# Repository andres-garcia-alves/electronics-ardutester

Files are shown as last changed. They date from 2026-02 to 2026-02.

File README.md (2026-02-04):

# ArduTester v1.08k OLED

Electronic project for use an Arduino Nano as an electronics components identifier.  
Schematics diagram + PCB diagram (KiCAD 9) and case 3D model (Blender) are also provided.  

This project is a **work-in-progress**.

Based on the well-known **TransistorTester** work of [Karl-Heinz Kübbeler](https://github.com/kubi48/).

Useful links:  
- [TransistorTester oficial GitHub](https://github.com/kubi48/TransistorTester-source)  
- [Mikrocontroller.net](https://www.mikrocontroller.net/articles/AVR_Transistortester)  
- [Mikrocontroller.net GitHub](https://github.com/Mikrocontroller-net/transistortester/)  

Aditional resources:
- [Electgpl@YouTube.com: Video tutorial: ArduTester + OLED display](https://www.youtube.com/watch?v=M8jgcR9IcJU) [spanish]
- [ElProfeGarcia@YouTube.com: Video tutorial: ArduTester component tester](https://www.youtube.com/watch?v=7o1T-6169ZE) [spanish]
- [Electronoobs@YouTube.com: Video tutorial: component test with Arduino + TFT display](https://www.youtube.com/watch?v=lsy2g0oz0Dk) [spanish]
- [Electronoobs.com blog](https://electronoobs.com/eng_arduino_tut191.php) [spanish]
- [BawejaAkshay@Instructables.com: ArduTester version #1](https://www.instructables.com/Component-Tester-Test-Almost-Anything-/)
- [BawejaAkshay@Instructables.com: ArduTester version #2](https://www.instructables.com/Component-Tester-in-a-Keychain/)
- [Lithium-Ion@Hackster.io blog](https://www.hackster.io/LithiumION/minimal-component-tester-using-arduino-b7b960)
- [RiverTrue@DFRobot.com blog](https://community.dfrobot.com/makelog-312328.html)
- [Plouc68000@ProjectHub.arduino.cc blog](https://projecthub.arduino.cc/plouc68000/ardutester-v113-the-arduino-uno-transistor-tester-2deffc)
- [ChristianIhle@GitHub.com blog](https://github.com/blurpy/transistor-tester)

&nbsp;

This project comes in two versions: `standard` (current) and `extended` (planned). See features bellow.

Features:
- One-key-operation.
- Three test pins for universal use.
- Automated detection of pin assignment, this means the device-under-test can be connected to the tester in any order.

Supported components:
- `Diodes`, `LEDs` and `Zeners`.
  - Diodes will also be displayed with their correctly aligned symbol, pin number, voltage drop, the parasitic capacitance and reverse current will also be measured.
- `Transistors` NPN/PNP BJT, JFET, N-channel/P-channel MOSFET.
  - Measurement of hFE and base-emitter-voltage for bipolar junction transistors, also for Darlingtons.
  - Automated detection of protection diodes in bipolar junction transistors and MOSFETs.
  - Bipolar junction transistors are detected as a transistor with a parasitic transistor (NPNp = NPN + parasitic PNP).
- `Resistors` will be measured with a resolution down to 0.1 ohm.  
  The measurement range is up to 50 Mohm (Megaohm).  
  Resistors below 10 ohm will be measured with the ESR approach and a resolution of 0.01 ohm.
- `Capacitors` in the range 35pF (picofarad) to 100mF (millifarad) can be measured with a resolution down to 1 pF.
  - Measurement of ESR (Equivalent Series Resistance) of capacitors greater than 20 nF is built in. 
  - Vloss of capacitors greater 5 nF is examined. With this it is possible to estimate its Q-factor.
- Resistors and capacitors will be displayed with their respective symbol, pin number and value.
- `Inductances` of 0.01 mH to 20 H can be detected and measured.
- Small `Thyristors` and `TRIACs`.

Notes:
- Be sure to **discharge capacitors** before measure it. Existing voltage can damage your Arduino.

&nbsp;

### List of Materials

The `standard` version uses the following electronic components:
- 1 x Arduino Nano v3
- 1 x OLED display 0.96" 128x64 I2C
- 3 x 680 ohm resistor
- 3 x 470k ohm resistor
- 1 x Push switch button
- 1 x 10k ohm resistor
- 1 x Socket connector 5-pins
- 1 x Bornier connector 2-pins / JST connector 2-pins
- 1 x Bornier connector 3-pins / JST connector 3-pins
- 1 x Bornier connector 4-pins / JST connector 4-pins
- Wires

&nbsp;

### Screenshots

| Breadboard | Assembly |
|---|---|
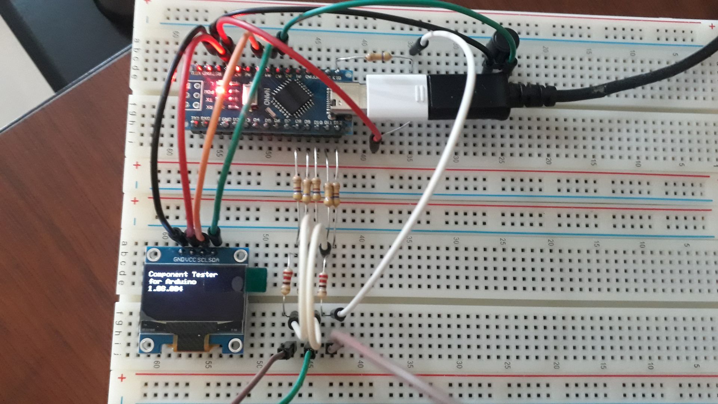
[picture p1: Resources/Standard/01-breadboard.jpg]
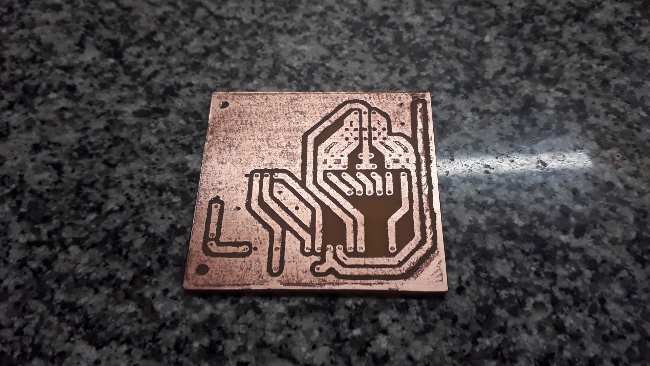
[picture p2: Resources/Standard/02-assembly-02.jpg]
|  |  |

| Assembly | Assembly |
|---|---|
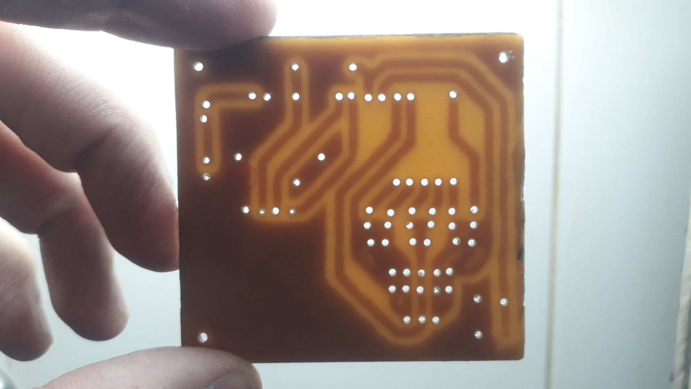
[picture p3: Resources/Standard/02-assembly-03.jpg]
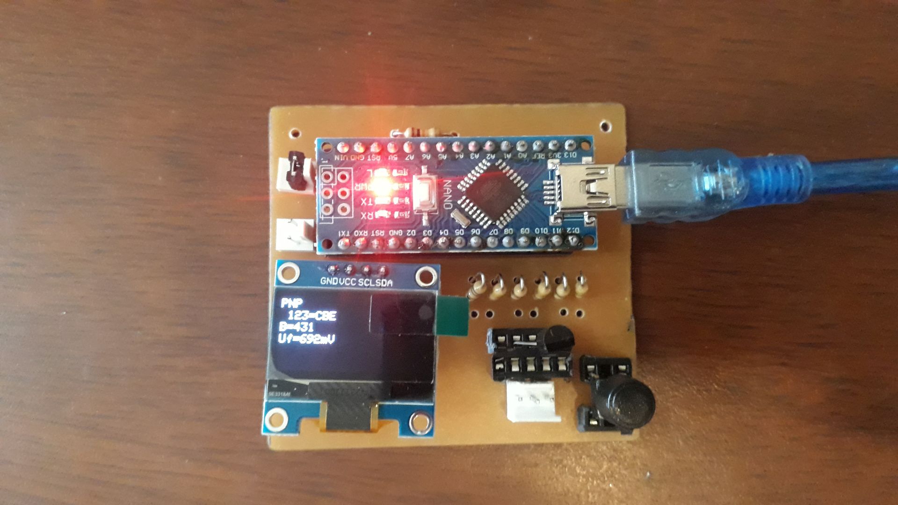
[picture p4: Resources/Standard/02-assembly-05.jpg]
|  |  |

| Schematics Diagram | PCB Diagram |
|---|---|
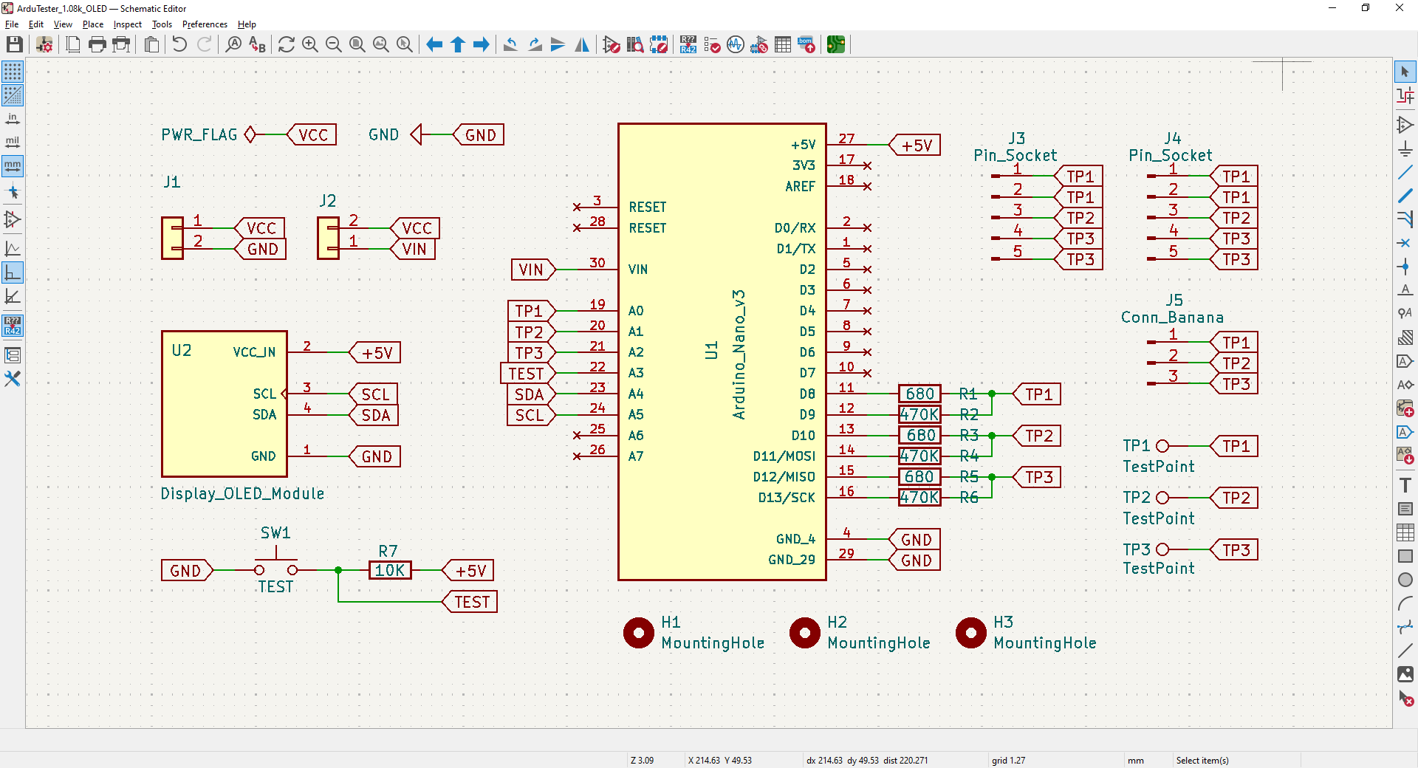
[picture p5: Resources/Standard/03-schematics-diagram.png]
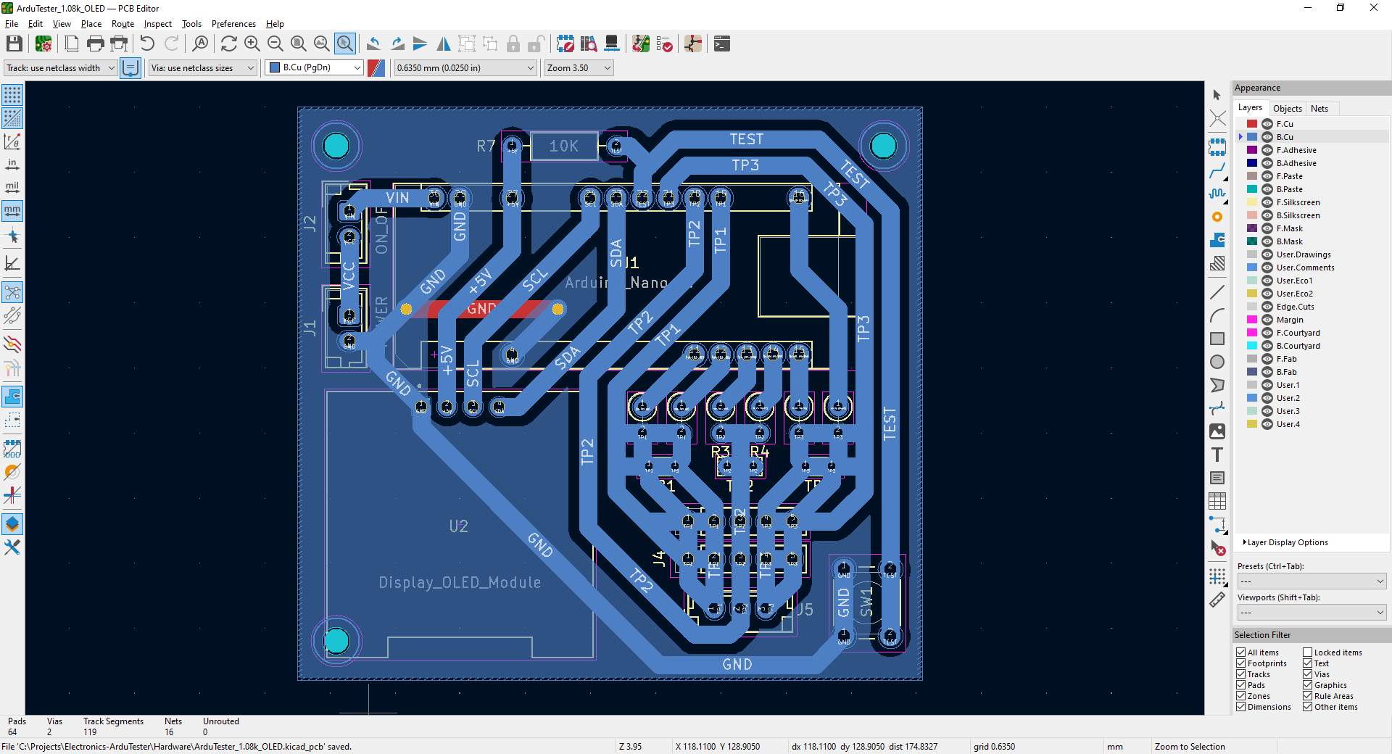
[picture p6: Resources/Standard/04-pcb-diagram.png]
|  |  |

| PCB Render 3D | PCB Render 3D |
|---|---|
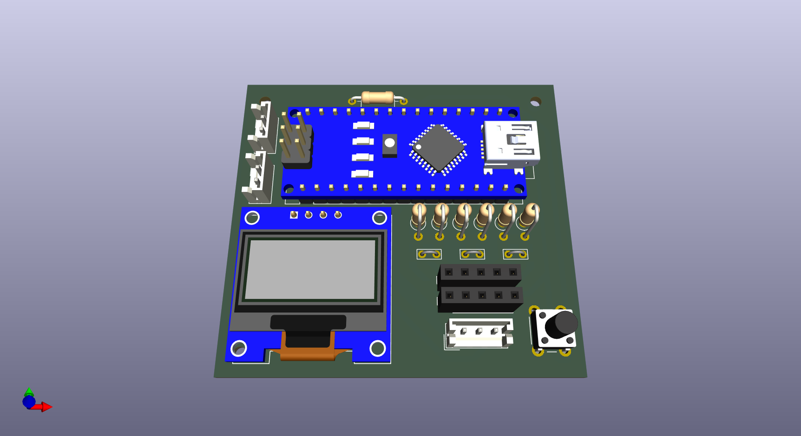
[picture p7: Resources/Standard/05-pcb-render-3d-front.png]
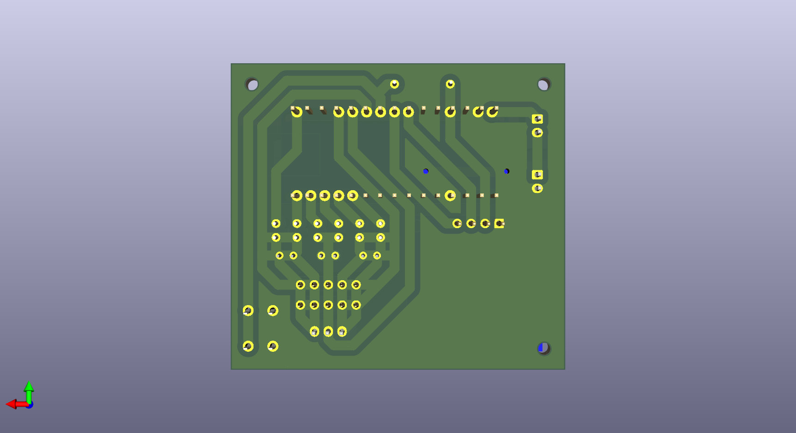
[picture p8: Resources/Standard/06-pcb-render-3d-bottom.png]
|  |   |

| Case 3D Model | Project Final |
|---|---|
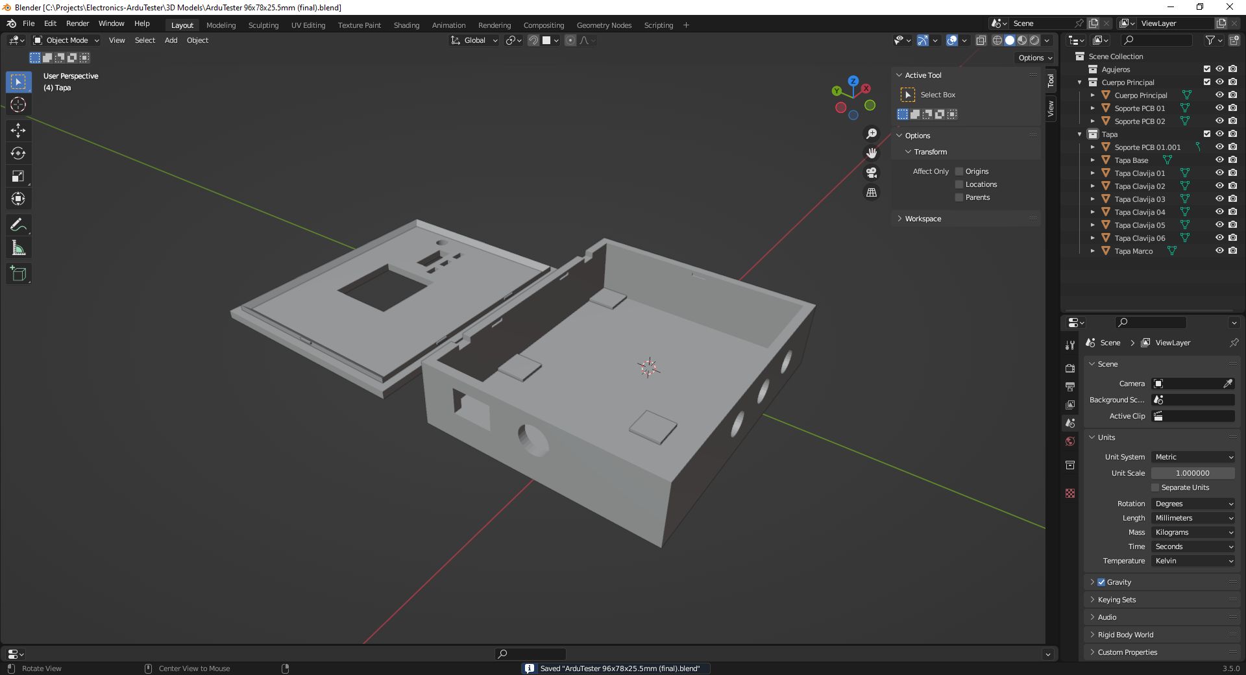
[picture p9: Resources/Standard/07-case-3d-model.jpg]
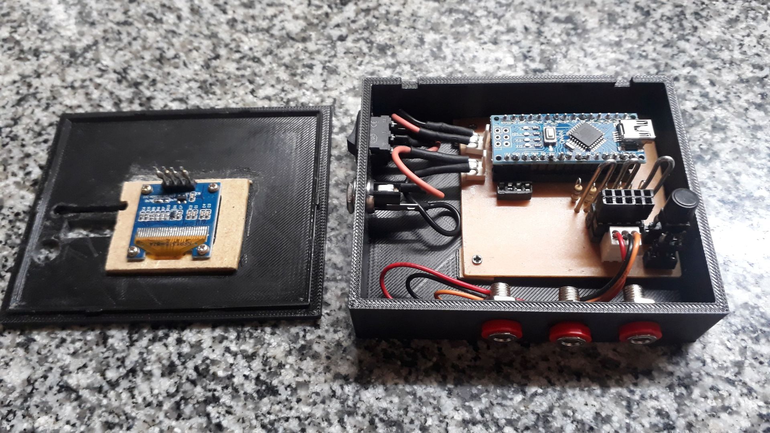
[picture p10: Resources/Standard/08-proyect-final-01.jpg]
|  |  |

| Project Final | Project Final |
|---|---|
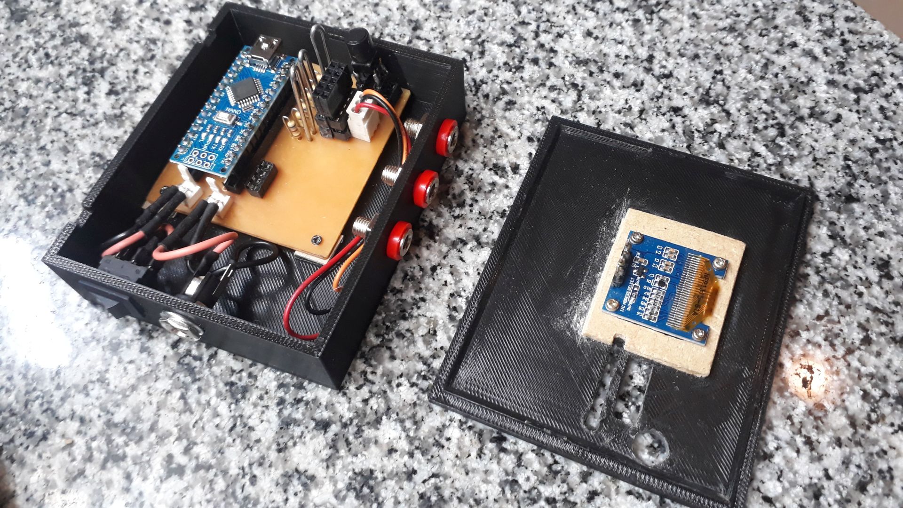
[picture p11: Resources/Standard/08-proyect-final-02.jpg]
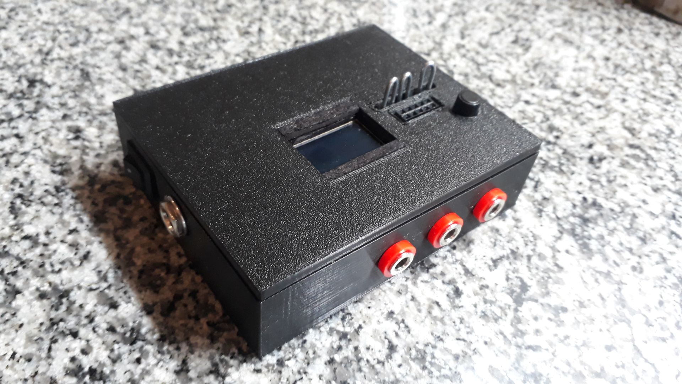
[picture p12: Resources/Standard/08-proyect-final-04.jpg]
|  |  |

See 'Resources' sub-folder for more pictures & videos of the project.

&nbsp;

### Version History

v1.0 (2026.01.04) - Initial release.  
v1.1 (2026.01.05) - Added schematics and PCB diagrams.  
v1.2 (2026.01.05) - Added 3D case model.  
v1.3 (2026.01.06) - Firmware and PCB fixes.  
v1.4 (2026.01.06) - 3D case model fixes.  
v1.4 (2026.01.06) - Minor case 3D model fixes.  
v1.5 (2026.01.09) - Minor fixes on PCB.  
v1.6 (2026.01.14) - Minor fixes on PCB.  
v1.7 (2026.01.16) - Re-design of PCB and 3D case model.  
v1.8 (2026.02.03) - Minor cases 3D model fixes.  
v1.9 (2026.02.04) - Added gadget images & video.  

&nbsp;

This source code is licensed under GPL v3.0  
Please send me your feedback about this project: andres.garcia.alves@gmail.com

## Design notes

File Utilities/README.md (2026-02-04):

## 🧪 Prueba A - Lectura de PINB (Entrada flotante)

📌 Objetivo

Verificar que los pines digitales D8–D13 (PB0–PB5) funcionen como entradas de alta impedancia cuando no hay nada conectado.

Sirve para detectar:
- Pull-ups internos activados permanentemente
- Puentes internos entre pines
- Fuga hacia GND o VCC
- PUERTO B dañado

🧠 Comportamiento esperado

En un Arduino sano:
- Los bits cambian continuamente
- No hay patrón fijo
- Algunos HIGH, otros LOW
- Excepción: pueden dat todos LOW según el Arduino (0)

En un Arduino dañado:
- Todo HIGH (111111)
- Patrón fijo que nunca cambia

🧾 Código:
<pre>
void setup() {
    Serial.begin(9600);
    DDRB = 0x00; // PB0–PB5 como entradas
}

void loop() {
    Serial.println(PINB & 0x3F, BIN);   // Lee solo PB0–PB5 delay(300);
}
</pre>

&nbsp;

## 🔁 Prueba B — PORTB salida → entrada (Test de conmutación digital)

📌 Objetivo:

Confirmar que los pines D8–D13 pueden:
- Conducir correctamente LOW y HIGH.
- Reflejar ese estado al leer PINB.

Detecta:
- Transistores MOSFET de salida quemados
- Pines pegados HIGH o LOW
- Puentes internos
- Fallo parcial de lógica digital

🧠 Comportamiento esperado

En un Arduino sano:
000000  
111111  
000000  
111111  
...

En un Arduino dañado:
- No cambia entre 0 y 1
- Bits faltantes (101011)
- Siempre HIGH o siempre LOW

🧾 Código
<pre>
void setup() {
    Serial.begin(9600);
    DDRB = 0x3F; // PB0–PB5 como salidas
}

void loop() {
    PORTB = 0x00;
    Serial.println(PINB & 0x3F, BIN);
    delay(300);
    PORTB = 0x3F;
    Serial.println(PINB & 0x3F, BIN);
    delay(300);
}
</pre>

&nbsp;

## 🎯 Prueba C — ADC A0/A1/A2 en vacío (Diagnóstico Analógico)

📌 Objetivo

Validar el sistema analógico completo:
- Multiplexor ADC (MUX)
- Capacitor Sample & Hold
- Comparador interno
- Referencia y acople entre canales

Detecta:
- ADC quemado por sobrevoltaje
- Fuga interna al VCC/GND
- MUX corrompido
- Diodos de protección dañados

🧠 Comportamiento esperado

En un Arduino sano:
- Números aleatorios
- Diferentes entre sí
- Rango típico: 50–600
- Cambian frame a frame

Ejemplo válido:
80   140  210
300   70  400
55   350  120

En un Arduino dañado:
- valores pegados a ~1023 → fuga a VCC
- valores pegados a ~0 → fuga a GND
- los tres iguales → crosstalk permanente

🧾 Código
<pre>
void setup() {
    Serial.begin(9600);
}

void loop() {
    Serial.print(analogRead(A0));
    Serial.print("\t");
    Serial.print(analogRead(A1));
    Serial.print("\t");
    Serial.println(analogRead(A2));
    delay(300);
}
</pre>

&nbsp;

## 🏁 Cómo usar los tres tests

1️⃣ Cargar Prueba A
✔ caos de bits → OK
✘ patrón fijo → no sirve para ArduTester

2️⃣ Si pasó, cargar Prueba B
✔ 0 ↔ 1 alterna completo → OK
✘ bits clavados → puerto digital dañado

3️⃣ Si pasó, cargar Prueba C
✔ ruido analógico variable → Nano apto
✘ todos iguales / 0 / 1023 → ADC dañado

&nbsp;

## 🏆 Conclusión

Si un Nano pasa los tres diagnósticos, está 100% apto para:
- ArduTester
- Medición analógica seria
- Proyectos con sensores
- Cualquier diseño donde se necesite precisión
- Si falla solo C, pero pasa A/B → podés usarlo para proyectos digitales solamente.

&nbsp;

## 🚀 Secuencia Automática

<pre>
// -----------------------------------------------------------
// SKETCH DIAGNÓSTICO PARA NANO
// Prueba A: Entrada flotante en PB (D8–D13)
// Prueba B: Conmutación digital LOW/HIGH en PB
// Prueba C: ADC en vacío (A0-A1-A2)
// Autor: armado especialmente para validar ArduTester
// -----------------------------------------------------------
void printBanner(const char *msg) {
    Serial.println();
    Serial.println(F("================================"));
    Serial.println(msg);
    Serial.println(F("================================"));
}
// -----------------------------------------------------------
// PRUEBA A — PB como entradas, lectura flotante
// -----------------------------------------------------------
void testA() {
    printBanner("PRUEBA A - Entrada flotante PB0-PB5");
    DDRB = 0x00; // D8-D13 como entradas
    for (int i = 0; i < 6; i++) {
        Serial.print("PINB = ");
        Serial.println(PINB & 0x3F, BIN);
        delay(300);
    }
}
// -----------------------------------------------------------
// PRUEBA B — PB como salida, alternando LOW/HIGH
// -----------------------------------------------------------
void testB() {
    printBanner("PRUEBA B - Conmutación PB0-PB5");
    DDRB = 0x3F; // D8-D13 como salidas
    for (int i = 0; i < 6; i++) {
        PORTB = 0x00;
        Serial.print("LOW -> ");
        Serial.println(PINB & 0x3F, BIN);
        delay(300);
        PORTB = 0x3F;
        Serial.print("HIGH -> ");
        Serial.println(PINB & 0x3F, BIN);
        delay(300);
    }
}
// -----------------------------------------------------------
// PRUEBA C — ADC en vacío A0/A1/A2
// -----------------------------------------------------------
void testC() {
    printBanner("PRUEBA C - Lectura ADC A0/A1/A2");
    for (int i = 0; i < 20; i++) {
        Serial.print(analogRead(A0));
        Serial.print("\t");
        Serial.print(analogRead(A1));
        Serial.print("\t");
        Serial.println(analogRead(A2));
        delay(300);
    }
}
void setup() {
    Serial.begin(9600);
    delay(1000);
    Serial.println();
    Serial.println(F("=== TEST COMPLETO DE ARDUINO NANO ==="));
    Serial.println(F("Ejecutando las 3 pruebas en bucle..."));
    Serial.println();
}
void loop() {
    testA();
    delay(800);
    testB();
    delay(800);
    testC();
    delay(1500);
    printBanner("FIN CICLO - Repitiendo");
    delay(5000);
}

</pre>

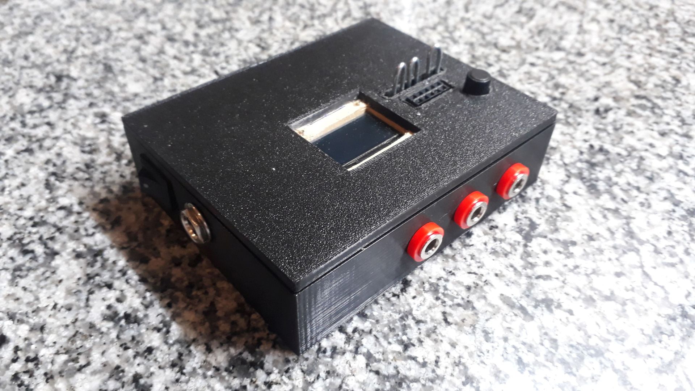
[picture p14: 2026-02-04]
Resources/Standard/08-proyect-final-03.jpg

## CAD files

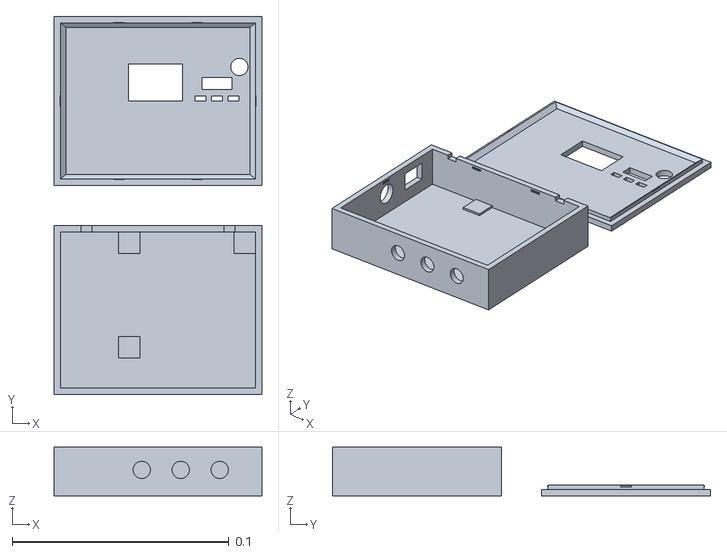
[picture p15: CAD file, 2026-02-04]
3D Models/ArduTester 96x78x25.5mm (final).stl
0.096 x 0.175 x 0.0225

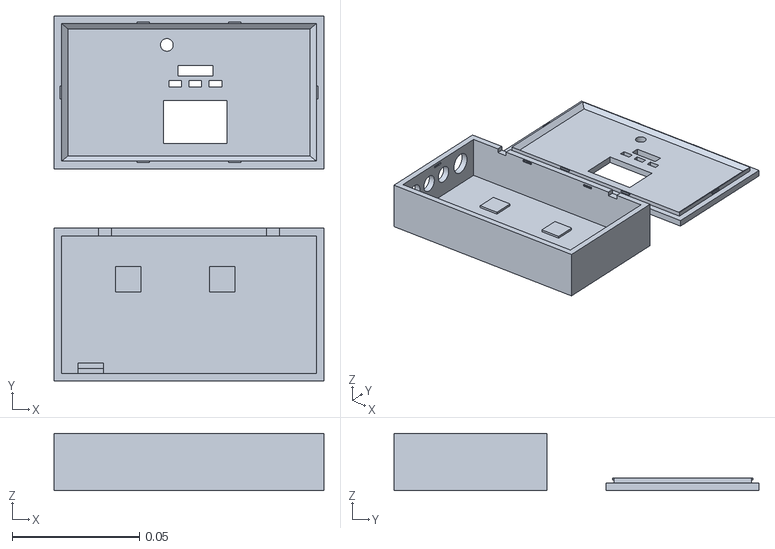
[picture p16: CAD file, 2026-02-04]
3D Models/ArduTester (Internal 9V Battery) 106x60x25.5mm (final).stl
0.106 x 0.143 x 0.0225

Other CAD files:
3D Models/ArduTester (Internal 9V Battery) 106x60x25.5mm (final).blend
3D Models/ArduTester (Internal 9V Battery) 106x60x25.5mm (without holes).blend
3D Models/ArduTester 96x78x25.5mm (final).blend
3D Models/ArduTester 96x78x25.5mm (without holes).blend

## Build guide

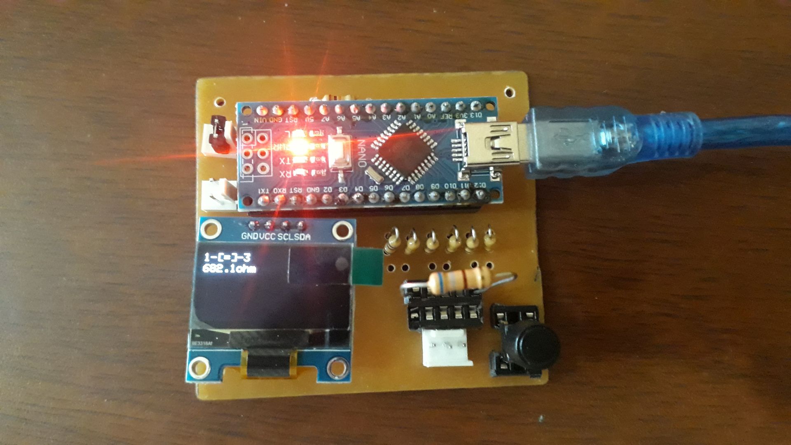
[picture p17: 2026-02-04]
Resources/Standard/02-assembly-04.jpg

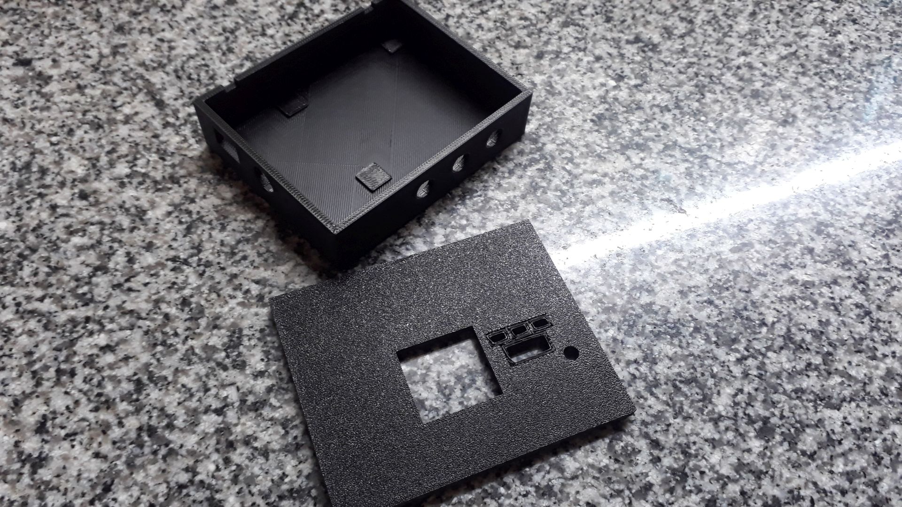
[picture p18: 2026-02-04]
Resources/Standard/07-case-3d-print.jpg

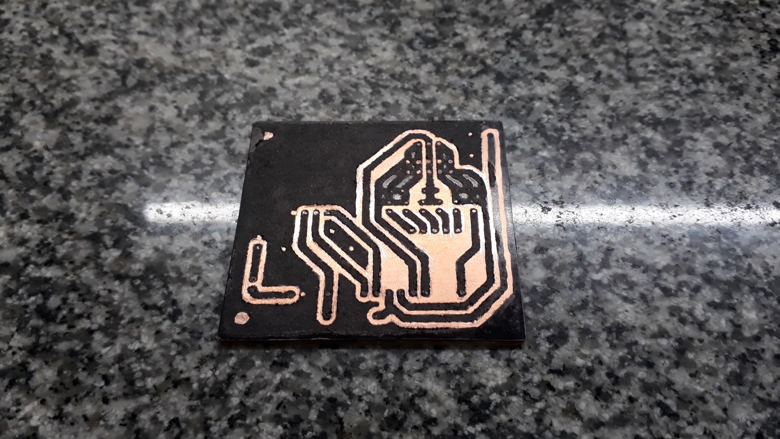
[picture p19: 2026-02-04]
Resources/Standard/02-assembly-01.jpg

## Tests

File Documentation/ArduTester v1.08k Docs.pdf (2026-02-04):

# TransistorTester with AVR microcontroller and a little more Version 1.08k

### Karl-Heinz K¨ubbeler

kh kuebbeler@web.de

### September 25, 2013

# Contents

1 Features | 4
2 Hardware | 7
3 Instructions for use | 15
4 Configuring the TransistorTester | 19
5 Description of the measurement procedures | 24

5.5 Selftest Function | 66
5.5.1 | Some Results of the Selftest Function | 70
6 Known errors and unsolved problems | 73
7 Special Software Parts | 74
8 To Do List and new ideas | 75

## Preface

### Basically Motive

Every hobbyist knows the following problem: You disassemle a Transistor out of a printed board or you get one out of a collection box. If you find out the identification number and you already have a data sheet or you can get the documents about this part, everything is well. But if you don’t find any documents, you have no idea, what kind of part this can be. With conventional approach of measurement it is difficult and time-consuming to find out the type of the part and parameters. It could be a NPN, PNP, N- or P-Channel-Mosfet etc. It was the idea of Markus F. to hand over the work to a AVR microcontroller.

### As my work has started

My work with the software of the TransistorTester of Markus F. [1] has started, because I had problems with my programmer. I had bought a printed board and components, but I could not program the EEprom of the ATmega8 with the Windows driver without error messages. Therefore I took the software of Markus F. and changed all the accesses from the EEprom memory to flash memory accesses. By analysing the software in order to save memory at other places of program, I had the idea, to change the result of the ReadADC function from ADC units to millivolt (mV) units. The mV resolution is needed for any output of voltage values. If ReadADC returns directly the mV resolution, I can save the conversion for each output value. This mV resolution can be get, if you first accumulate the results of 22 ADC readings. The sum must be multiplied with two and divided by nine. Then we have a maximum value of 1023·22·2
9 = 5001, which matches perfect to the wanted mV resolution of measured voltage values. So I additionally had the hope, that the enhancement of ADC resolution by oversampling could help to improve the voltage reading of the ADC, as described in AVR121 [5]. The original version ReadADC has accumulated the result of 20 ADC measurements and divides afterwards by 20, so the result is equal to original ADC resolution. By this way never a enhancement of ADC resolution can take place. So I had to do little work to change the ReadADC, but this forced analysing the whole program and change of all “if-statements” in the program, where voltage values are queried. But this was only the beginning of my work!

More and more ideas to make measurement faster and more accurate has been implemented. Additionally the range of resistor and capacity measurements are extended. The output format for LCD-Display was changed, so symbols are taken for diodes, resistors and capacitors instead of text. For further details take a look to the actual feature list chapter 1. Planned work and new ideas are accumulated in the To Do List in chapter 8. By the way, now I can program the EEprom of the ATmega with Linux operating system without errors.
At this place I would like to thank the originator and software author Markus Frejek, who has enabled the continuation with his initial work. In addition I would like to say thanks to the authors of numerous input to the discussion forum, which have assist me, to find new tasks, weak points and errors. Next I would like to thank Markus Reschke, who give me the permission, to publish his cheerful software versions at the SVN server. Furthermore some ideas and software part of Markus
R. was integrated in my own software version, again thank you very much. I have to thank also Asco B., who has developed a new printed board, to enable the reproductions for other hobbyists. Another thank I would like to send to Dirk W. , who has handled the omnibus order for this printed board. Never I had time anough to handle these things concurrently with my software developement, at no time the state of further developement of software would have the same level. Thanks for the many suggestions to improve the tester to the members of the local chapter of the ”Deutscher Amateur Radio Club (DARC)” in Lennestadt.

# Chapter 1

# Features

1. Operates with ATmega8, ATmega168 or ATmega328 microcontrollers.
2. Displaying the results to a 2x16 character LCD-Display.
3. One key operation with automatic power shutdown.
4. Battery operation is possible since shutdown current is only about 20nA.
5. Low cost version is feasible without crystal and auto power off. With software version 1.05k the sleep modus of the Atmega168 or ATmega328 is used to reduce current if no measurement is required.
6. Automatic detection of NPN and PNP bipolar transistors, N- and P-Channel MOSFETs, JFETs, diodes, double diodes, Thyristors and Triacs.
7. Automatic detection of pin layout of the detected part.
8. Measuring of current amplification factor and Base-Emitter threshold voltage of bipolar transistors.
9. Darlington transistors can be identified by the threshold voltage and high current amplification factor.
10. Detection of the protection diode of bipolar transistors and MOSFETs.
11. Measuring of the Gate threshold voltage and Gate capacity value of MOSFETs.
12. Up to two Resistors are measured and shown with symbols | and values with up to four
decimal digits in the right dimension. All symbols are surrounded by the probe numbers of the Tester (1-3). So Potentiometer can also be measured. If the Potentiometer is adjusted to one of its ends, the Tester cannot differ the middle pin and the end pin.
13. Resolution of resistor measurement is now up to 0.01Ω, values up to 50MΩ are detected.
14. One capacitor can be detected and measured. It is shown with symbol and value with up to four decimal digits in the right dimension. The value can be from 25pF (8MHz clock, 50pF @1MHz clock) to 100mF. The resolution can be up to 1 pF (@8MHz clock].
15. For capacitors with a capacity value above 0.18µF the Equivalent Serial Resistance (ESR) is measured with a resolution of 0.01Ω and shown with two significant decimal digits. This feature is only avaiable for ATmega with at least 16K flash memory (ATmega168 or ATmega328).

16. For capacitors with a capacity value above 5000pF the voltage loss after a load pulse can be determined. The voltage loss give a hint for the quality factor of the capacitor.
17. Up to two diodes are shown with symbol | or symbol | in correct order. Additionally
the flux voltages are shown.
18. LED is detected as diode, the flux voltage is much higher than normal. Two-in-one LEDs are also detected as two diodes.
19. Zener-Diodes can be detected, if reverse break down Voltage is below 4.5V. These are shown as two diodes, you can identify this part only by the voltages. The outer probe numbers, which surround the diode symbols, are identical in this case. You can identify the real Anode of the diode only by the one with break down (threshold) Voltage nearby 700mV!
20. If more than 3 diode type parts are detected, the number of founded diodes is shown additionally to the fail message. This can only happen, if Diodes are attached to all three probes and at least one is a Z-Diode. In this case you should only connect two probes and start measurement again, one after the other.
21. Measurement of the capacity value of a single diode in reverse direction. Bipolar Transistors can also be analysed, if you connect the Base and only one of Collector or Emitter.
22. Only one measurement is needed to find out the connections of a bridge rectifier.
23. Capacitors with value below 25pF are usually not detectet, but can be measured together with a parallel diode or a parallel capacitor with at least 25pF. In this case you must subtract the capacity value of the parallel connected part.
24. For resistors below 2100Ω also the measurement of inductance will be done, if your ATmega has at least 16K flash memory. The range will be from about 0.01mH to more than 20H, but the accuracy is not good. The measurement result is only shown with a single component connected.
25. Testing time is about two seconds, only capacity or inductance measurement can cause longer period.
26. Software can be configured to enable series of measurements before power will be shut down.
27. Build in selftest function with optional 50Hz Frequency generator to check the accuracy of clock frequency and wait calls (ATmega168 and ATmega328 only).
28. Selectable facility to calibrate the internal port resistance of port output and the zero offset of capacity measurement with the selftest (ATmega168 and ATmega328 only). A external capacitor with a value between 100nF and 20µF connected to pin 1 and pin 3 is necessary to compensate the offset voltage of the analog comparator. This can reduce measurement errors of capacitors of up to 40µF. With the same capacitor a correction voltage to the internal reference voltage is found to adjust the gain for ADC measuring with the internal reference.

Thyristors and Triacs can only be detected, if the test current is above the holding current. Some Thyristors and Triacs need as higher gate trigger current, than this Tester can deliver. The available testing current is only about 6mA! Notice that all features can only be used with microcontroller with more program memory such as ATmega168.

Attention: Allways be shure to discharge capacitors before connecting them to the Tester! The Tester may be damaged before you have switched it on. There is only a little protection at the ATmega ports.
Extra causion is required if you try to test components mounted in a circuit. In either case the equipment should be disconnected from power source and you should be shure, that no residual voltage remains in the equipment.

# Chapter 2

# Hardware

## 2.1 Circuit of the TransistorTester

The circuit of the TransistorTester in figure 2.1 is based on the circuit of Markus F. released in Abb. 1 of AVR-Transistortester report [1]. Changed or moved parts are marked with green color, optional parts are marked with red color.
Some changes are made because the electronical power switch make problems in some implemen-tations. Therefore the resistor R7 is reduced to 3.3kΩ. The capacitor C2 is reduced to 10nF and R8 is moved so that the PD6 output does not try to switch the C2 capacitor directly. Additional blocking capacitors are added and should be placed near the power connection of the Atmega and near the Voltage regulator.
Because the PD7 input and PC6 (RESET) are the only pins, where pull up resistors where needed, one extra 27kΩ resistor is added to the PD7 (pin 13) input. With this modification the software can disable all internal pull up resistors of the ATmega.
The additional crystal with its 22pF capacitors are optional added. The accuracy of a crystal has the benefit of more stable time measurement for getting the capacitor values.
New software version can use a voltage scale switch of the ADC. The speed of switching is reduced by the external capacitor C1 at the AREF (21) pin of the ATmega. To avoid slowing down the measurement speed more than necessary, the value of this capacitor should be reduced to 1nF. Removing of the capacitor C1 is also possible. For adapting the software to the actual circuit take a look to the Makefile options in the configuring chapter 4.
Some different versions of R11 / R12 resistor combinations circulates in the internet. I have adapted my software to the original of Markus F. [1] with 10kΩ and 3.3kΩ.
The additional 2.5V precision voltage reference connected at pin PC4 (ADC4) can be used to check and calibrate the VCC voltage, but is not required. You can use a LM4040-AIZ2.5 (0.1%), a LT1004CZ-2.5 (0.8%) or a LM336-Z2.5 (0.8%) as voltage reference. A optional ISP connector has been added to easier load new software versions to the tester.

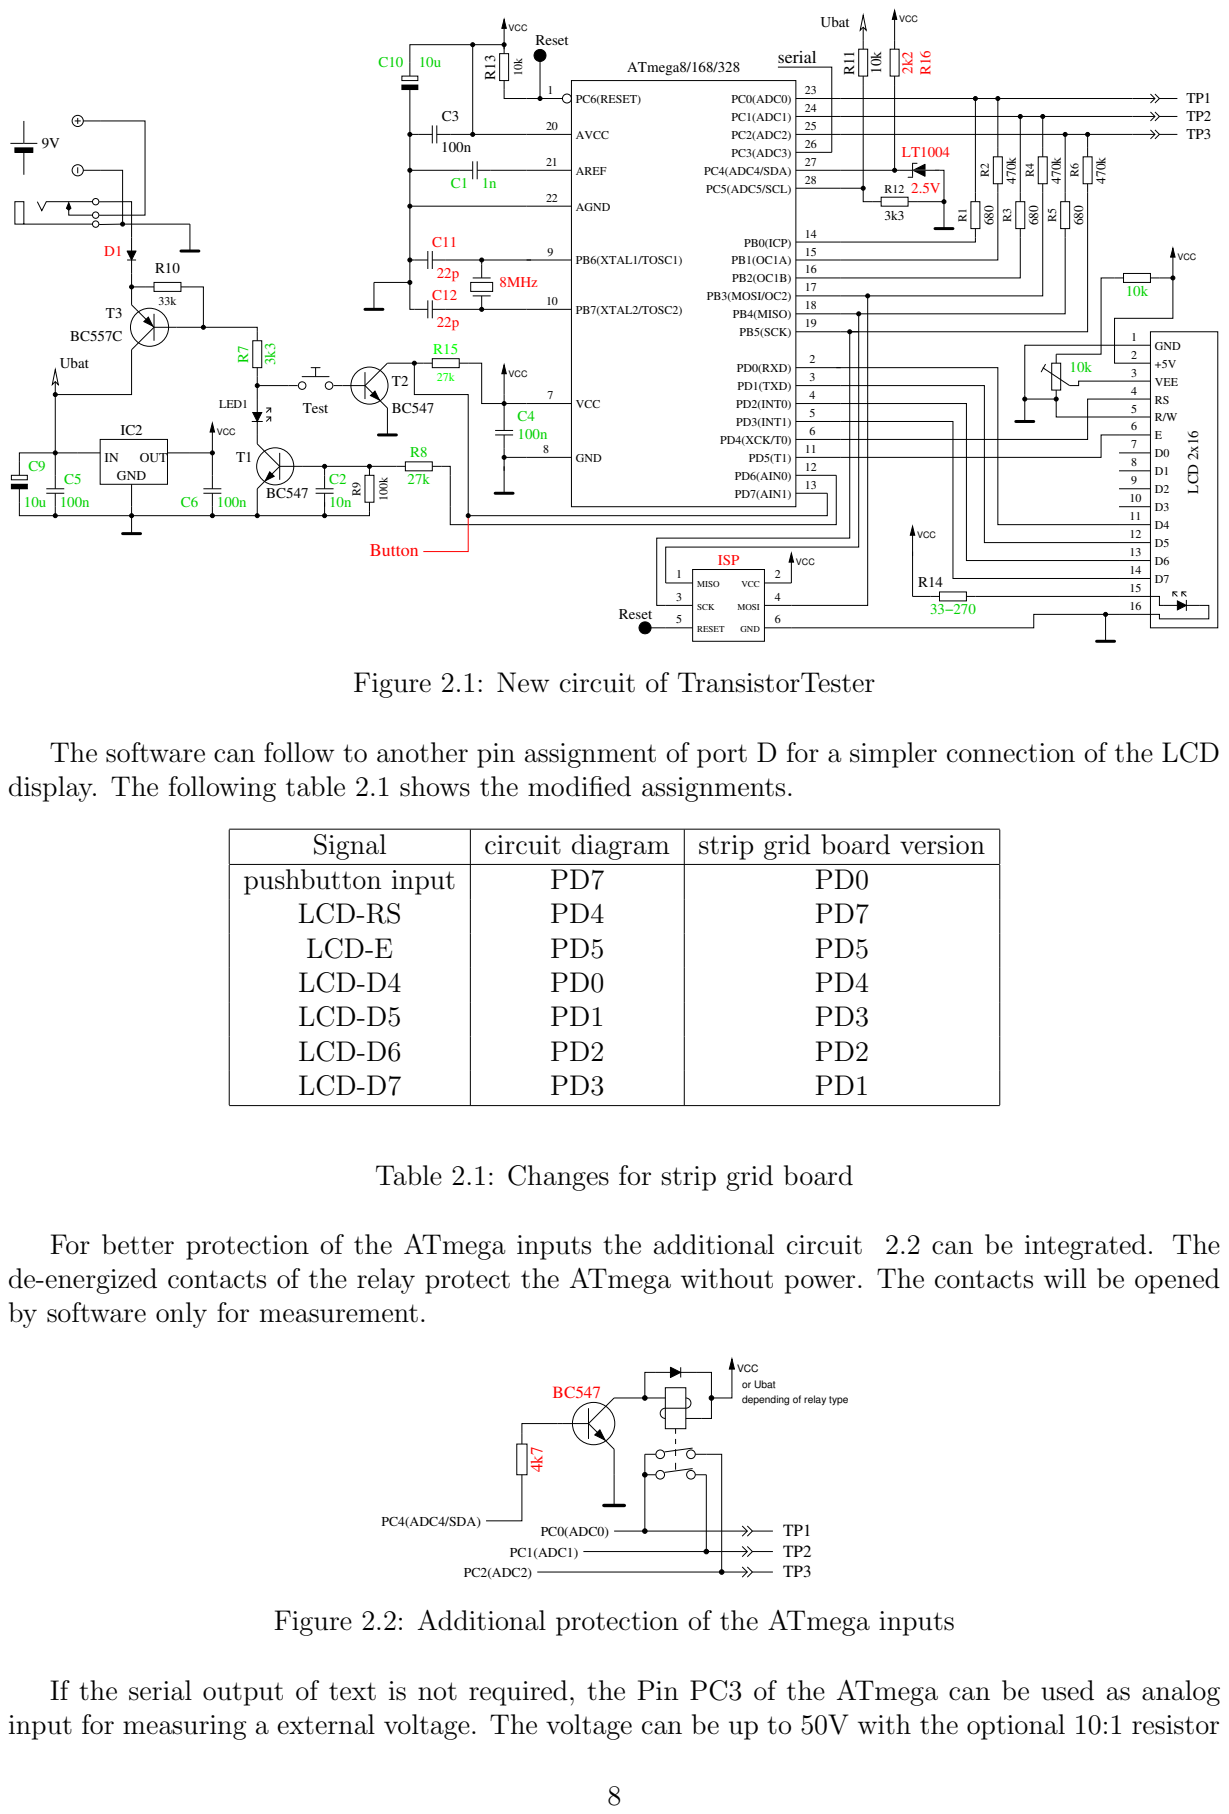
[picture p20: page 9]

Figure 2.1: New circuit of TransistorTester

The software can follow to another pin assignment of port D for a simpler connection of the LCD
display. The following table 2.1 shows the modified assignments.

Signal | circuit diagram | strip grid board version
pushbutton input LCD-RS LCD-E LCD-D4 LCD-D5 LCD-D6 LCD-D7 | PD7 PD4 PD5 PD0 PD1 PD2 PD3 | PD0 PD7 PD5 PD4 PD3 PD2 PD1

Table 2.1: Changes for strip grid board

For better protection of the ATmega inputs the additional circuit 2.2 can be integrated. The
de-energized contacts of the relay protect the ATmega without power. The contacts will be opened
by software only for measurement.

VCC Figure 2.2: Additional protection of the ATmega inputs

or Ubat
depending of relay type

If the serial output of text is not required, the Pin PC3 of the ATmega can be used as analog
input for measuring a external voltage. The voltage can be up to 50V with the optional 10:1 resistor

divider and can be used for measuring the breakdown voltage of a zener diode. A current limiting power supply with up to 50V can be switched on with low signal at PD7 pin of the ATmega to deliver current for testing the break down voltage of a zener diode. Figure 2.3 shows a suggestion for this expansion. The tester shows the external voltage as long as you hold the key pressed. About 40mA more battery current is used by this expansion during key pressing.

Vin+

Vin−

Com DC−DC Conv.

Vout+15

Vout−15

R18

180k

R17

20k

10n

serial / PC3

External
Voltage

1uF

33uH

L1

C13

Uext
10k

TMA0515D

T4
Uext

Button

R19

Ubat

C15

100n

Can be placed on Tester board! Should be placed separate!

IN OUT

IC3

GND

MCP1702

IRFU9024

C17

C16

50u 100n
C14

Figure 2.3: Expansion for measuring of break down voltage of Zener diodes

## 2.2 Hints for building the TransistorTester

Every LCD-display with at least 2x16 character and a HD44780 compatible controller can be used with the TransistorTester. You should respect the current needed for illumination, some LCD need lower current than others. I had tried OLED type displays, but this type cause interference with measurements of the ATmega and are not recommended. Also loading of special characters for displaying the resistor symbol has caused problems with the OLED.
The resistors R1 to R6 are critical for measurements and this 680Ω and 470kΩ resistors should be measurement type resistors (tolerance of 0.1%) to get the full accuracy. You should use a precision socket for the ATmega microcontroller to enable the replacement of the microcontroller. The microcontroller ATmega8, ATmega168 and ATmega328 can be used. Recommended is a ATmega168 or ATmega328, if you wish to use all features.
Anyway you should assemble all parts to printed board without the microcontroller. A up-to-date low voltage drop regulator like MCP1702-5002 is recommended as IC2, because it need only 2µA of standby current and can still deliver 5V, if your input voltage is only 5.4V. But this part is not pin compatible to well known 78L05 with TO92 body!
After checking, that all needed parts are at the correct place, you should first connect the battery or power supply to the printed board without LCD-display and microcontroller. You should check the voltage at the power pins of the microcontroller and LCD-display terminal during the Test key is pressed. The voltage should disappear, if you release the Test key. If the voltage had correct polarity and value, you should disconnect the power and assemble the microcontroller with correct alignment. Be careful and make shure, that all pins of the microcontroller are in the socket holes. Now you can also connect the LCD. Check if power pins of the LCD has the right connection to GND and VCC of your board.
If you are shure that everything is all right, reconnect the power. If you have already programmed the ATmega, you can press the Test button. By pressing the Test key, the background light of the LCD should switch on. If you release the Test button, the LED should illuminate weak. Notice, that the software for the microcontroller must be compiled for the correct processor type. A program for the ATmega8 does not run on a ATmega168!

2.3 Changeover for tester versions designed by Markus F.

Voltage control If the problem exist, the tester will shut down immediately with every switch on. With imy suggested setting of the fuses (Makefile) the voltage control of the different ATmega versions is switched to 4V (brown out level). This may be the reason why the tester makes trouble with the power on sequence. The Pin PD6 tries to switch the 100nF capacitor C2 to VCC level causing a voltage breakdown of the VCC voltage (5V). The capacitor C2 can be reduced to <10nF without problems. If possible, the direct connection of PD6 should be replaced by a resistor >220Ω.

Improvement of power on circuit Often this problem is the reason, if the tester starts with the button hold pressed, but switch off directly by releasing. The problem is enforced by a high current background light for the LCD. The resistor R7 to the base of the PNP transistor T3 was optimized with the value 27kΩ too much to save power consuming. To improve the switching with lower battery voltage or lower current amplification factor of the PNP transistor T3, you should reduce the resistance to 3.3kΩ.

Additional pull-up resistor at PD7 The missing pull-up resistor results to a switch off of the tester with the message ”Timeout” after a short display time. The software is configured with the option PULLUP DISABLE, that all internal pull-up resistors are switched off. For that reason the voltage of pin PD7 is not definded, if the level is not switched by the push button or transistor T2 to GND. One external pull-up resistor of 27kΩ to VCC avoid this error.

Capacitor C1 at the AREF pin Many designs use a 100nF capacitor at the AREF pin, like the design of Markus F. too. As long as the reference voltage of the ADC is never changed, this is a good solution. The software of the TransistorTester for the ATmega168/328 uses a automatic selection of the internal 1.1 V reference voltage of the ADC, if the input voltage is below 1V. With this solution a better resolution of the ADC can be reached for little input voltages. Unfortunately the switching from 5V to 1.1V reference is very slowly. A additional wait time of 10ms must be respected for this reason. With changing the capacity value to 1nF this wait time can be reduced significant. I have not noticed any degration of measurement quality with this change. Even a removing of the capacitor has no significant change of measurement results. If you prefer to leve the capacitor unchanged, you can remove the option NO AREF CAP in the Makefile to activate longer wait times in the program.

Expanding of a 8MHz crystal With some skill you can expand a 8MHz crystal to the backside of the printed board directly to the pins PB6 and PB7 (pin 9 and pin 10). My own expansion was done without the both 22pF capacitors. This solution has operated well with all tested ATmega. But it is not required to use a crystal. You can still use the 8MHz RC oszillator by setting the fuses to get the better resolution of time constant measuring (capacity value).

Smoothing of the operating voltage The original circuit of Markus F. shows only one 100nF capacitor to block the VCC voltage. This is clearly too little smoothing. You should at least use one 100nF near the ATmega power pins and one near the voltage regulator. The input of the voltage regulator should be blocked with a 100nF too. Additional 10µF capacitors (electrolytic or ceramic) at the input and output of the voltage regulator can stable the voltage level. Ceramic 10µF capacitos with SMD mounting form are easier to use for backfitting and have usually a lower ESR value.

Selection of the ATmega processor The using of the base function of the tester is still possible with a ATmega8. The flash memory of that device is used near 100% . Because the ATmega168 or ATmeg328 processors are pin-compatible to the ATmega8, I can recommend the replacement. Actually the price for ATmega328 is so cheap, that there is no reason to take a ATmega168 type. With a ATmega168/328 you get the following advantages: Self test with automatic calibration.
Improvement of measurement quality by automatic switching of ADC scale.

Measurement of inductors with resistance below 2100Ω. Measurement of ESR value of capacitors with value of above 0.18µF. The resolution of resistor measurement below 10Ω is 0.01Ω.
Using of pin PC4 as serial output.

Missing precision voltage reference Usually the software should detect the missing voltage reference with the unconnected pin PC4. In this case no VCC=x.xV message should appear in row 2 of the LCD on power on. If this message appear without the reference, you should connect a 2.2kΩ resistor to the PC4 input and VCC.

## 2.4 Chinese clones

As I know, the tester is rebuild in China in two versions. The first model is rebuild from the first design of Markus F. without the ISP port. The assembled ATmega8 is placed in a socket, so you can replace it with a ATmega168 or ATmega328. For this version you should consider all the hints of section 2.3. Additional 100nF ceramic cpacitors should be connected near by the VCC-GND and AVCC-GND pins of the ATmega for better stabilization of the power voltage. In addition you should notice, that if you expand the board with the additional 8 MHz crystal, your external ISP programmer must have a external clock for programming.

The second version of rebuilded tester is build with SMD components. Also the fix installed ATmega168 is a SMD type with 32TQFP body. Fortunately on the board is a 10-pole ISP connector provided for the programming. I have analysed the board version ”2.1 2012/11/06”. One error is the assembly of the part ”D1”, which should be a precision 2.5V voltage reference. Assembled is only a zener diode. This part should be removed. You can mount a LM4040AIZ2.5 or LT1004CZ-2.5 precision voltage reference at this place. A missing voltage reference is noticed by the software, so that you must not install the voltage reference. My exemplar was delivered with software version 1.02k. The 10-pole ISP plug was not assembled and I must install a jumper from ISP pin 6 to ISP pin
10. My programmer expect a GND connection at pin 10, but the board has GND level only on pin 4 and pin 6 of the ISP. The label of the ATmega168 was rub away and there was no documentation delivered with the part. The lock fuses of the ATmega were set, so no readout was possible. But I could install the software version 1.05k without any problems. Another user has problems with the same software version 1.05k. This user has the chinese board ”2.2 2012/11/26”. The software runs only without problems, if a additional 100nF keramic capacitor was placed between the pin 18-AVCC and 21-GND near by the ATmega. The software 1.05k uses the sleep state of the ATmega for waiting time. For this reason the current alternates often and the voltage regulator is stressed more. Further I have noticed, that the VCC voltage is blocked with a 100nF ceramic capacitor and with a 220µF electrolytic capacitor nearby the 78L05 voltage regulator. The 9V supply voltage is blocked with the same capacitors, but not at the input of the regulator but at the emitter of the PNP transistor (parallel with the battery). The printed circuit board track from the ATmega168 to the test port is very thin, so that a resistance of 100mΩ could be measured for one path. This will be the reason for measuring a resistance of 0.3Ω for two direct connected pins. The ESR measuring can usually consider this by zero compensation. Beginning with version 1.07k the software does respect this offset for measuring resistors below 10Ω too.
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

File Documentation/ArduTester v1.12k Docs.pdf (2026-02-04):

# TransistorTester with AVR microcontroller and a little more Version 1.12k

### Karl-Heinz K¨ubbeler

kh kuebbeler@web.de

### February 18, 2017

# Contents

1 Features | 5
2 Hardware | 9
3 Instructions for use | 38
4 Configuring the TransistorTester | 47

5 Description of the measurement procedures | 58
5.1 Measurement of Semiconductors | 60
5.1.1 | Measurement of PNP Transistor or P-Channel-MOSFET | 61
5.1.2 | Measurement of NPN Transistor or N-Channel-MOSFET | 63
5.1.3 | Simplified flowchart of the transistors tests | 66
5.1.4 | Measurement of Diodes | 68
5.1.5 | Results of different measurements | 69
5.2 Resistor Measurement | 73
5.2.1 | Resistor Measurement with 680 Ohm Resistors | 73
5.2.2 | Resistor Measurement with 470 kOhm resistors | 75
5.2.3 | Results of the resistor measurements | 76
5.3 Measurement of Capacitors | 81
5.3.1 | Discharging of Capacitors | 81
5.3.2 | Measurement of big Capacitors | 81
5.3.3 | Measurement of small Capacitors | 84
5.3.4 | Measurement of very small capacity values with the sampling technique . . . . 86
5.3.5 | Measurement of the Equivalent Series Resistance ESR | 87
5.3.6 | Measurement of the Equivalent Series Resistance ESR, first way | 89
5.3.7 | Measurement of the Equivalent Series Resistance ESR, second way | 92
5.3.8 | Voltage loss after a load pulse, Vloss | 99
5.3.9 | Separate capacity and ESR measurement | 100
5.3.10 Results of Capacitor measurement | 101
5.3.11 Automatic calibration of the capacitor measurement | 105
5.4 Measurement of inductance | 109
5.4.1 | Results of the inductance measurements | 110
5.4.2 | Measurement of small inductances with the sampling method | 110
5.5 Selftest Function | 112
5.5.1 Some Results of the Selftest Function | 116
5.6 Measurement of frequency | 120
6 Signal generation | 122
6.1 Frequency Generation | 122
6.2 Puls width generation | 122
7 Known errors and unsolved problems | 123
8 Special Software Parts | 124
9 To Do List and new ideas | 125

## Preface

### Basically Motive

Every hobbyist knows the following problem: You disassemle a Transistor out of a printed board or you get one out of a collection box. If you find out the identification number and you already have a data sheet or you can get the documents about this part, everything is well. But if you don’t find any documents, you have no idea, what kind of part this can be. With conventional approach of measurement it is difficult and time-consuming to find out the type of the part and parameters. It could be a NPN, PNP, N- or P-Channel-Mosfet etc. It was the idea of Markus F. to hand over the work to a AVR microcontroller.

### As my work has started

My work with the software of the TransistorTester of Markus F. [1] has started, because I had problems with my programmer. I had bought a printed board and components, but I could not program the EEprom of the ATmega8 with the Windows driver without error messages. Therefore I took the software of Markus F. and changed all the accesses from the EEprom memory to flash memory accesses. By analysing the software in order to save memory at other places of program, I had the idea, to change the result of the ReadADC function from ADC units to millivolt (mV) units. The mV resolution is needed for any output of voltage values. If ReadADC returns directly the mV resolution, I can save the conversion for each output value. This mV resolution can be get, if you first accumulate the results of 22 ADC readings. The sum must be multiplied with two and divided by nine. Then we have a maximum value of 1023·22·2
9 = 5001, which matches perfect to the wanted mV resolution of measured voltage values. So I additionally had the hope, that the enhancement of ADC resolution by oversampling could help to improve the voltage reading of the ADC, as described in AVR121 [5]. The original version ReadADC has accumulated the result of 20 ADC measurements and divides afterwards by 20, so the result is equal to original ADC resolution. By this way never a enhancement of ADC resolution can take place. So I had to do little work to change the ReadADC, but this forced analysing the whole program and change of all “if-statements” in the program, where voltage values are queried. But this was only the beginning of my work!

More and more ideas to make measurement faster and more accurate has been implemented. Additionally the range of resistor and capacity measurements are extended. The output format for LCD-Display was changed, so symbols are taken for diodes, resistors and capacitors instead of text. For further details take a look to the actual feature list chapter 1. Planned work and new ideas are accumulated in the To Do List in chapter 9. By the way, now I can program the EEprom of the ATmega with Linux operating system without errors.
At this place I would like to thank the originator and software author Markus Frejek, who has enabled the continuation with his initial work. In addition I would like to say thanks to the authors of numerous input to the discussion forum, which have assist me, to find new tasks, weak points and errors. Next I would like to thank Markus Reschke, who give me the permission, to publish his cheerful software versions at the SVN server. Furthermore some ideas and software part of Markus R. was integrated in my own software version, again thank you very much. Also Wolfgang SCH. has done a great job to support a graphical display with ST7565 controller. Many thanks to him for integrating his patch for 1.10k software version to the actual developer version. I have to thank also Asco B., who has developed a new printed board, to enable the reproductions for other hobbyists. Another thank I would like to send to Dirk W. , who has handled the omnibus order for this printed board. Never I had time anough to handle these things concurrently with my software developement, at no time the state of further developement of software would have the same level. Thanks for the many suggestions to improve the tester to the members of the local chapter of the

”Deutscher Amateur Radio Club (DARC)” in Lennestadt. Also I would like to say thanks for the integration of the sampling method to the radio amateur Pieter-Tjerk (PA3FWM). With this method the measurement of little capacity and inductance values could be improved noticeable. Last but not least I would say thanks to Nick L. from Ukraine, who has supported my with his prototype boards, has suggested some hardware add ons and also has organized the russian translation for this description.

# Chapter 1

# Features

1. Operates with ATmega8, ATmega168 or ATmega328 microcontrollers. Additionally ATmega644, ATmega1284, ATmega1280 or ATmega2560 microcontrollers can be used.
2. Displaying the results to a 2x16 or a 4x16 character LCD-Display. If the processor have at least 32K flash memory, also a graphical display with 128x64 pixel and a ST7565, ST7920, ST7108, KS0108 or a SSD1306 controller can be used. In doing so a 4-wire SPI interface or a I

2C bus must be used instead of the 4-bit parallel interface for the SSD1306 controller. Even color displays with ILI9163 or ST7735 controller are usable with the SPI interface. For the ST7108 or KS0108 controller you must use a serial - parallel interface with a 74HC(T)164 or a 74HC(T)595. Displays with PCF8812 or PCF8814 controller can be only used without the big icons for transistors, because the display size is unsufficient (102x65 and 96x65).

3. One key operation with automatic power shutdown.
4. Battery operation is possible since shutdown current is only about 20nA.
5. Low cost version is feasible without crystal and auto power off. With software version 1.05k the sleep modus of the Atmega is used to reduce current if no measurement is required and no rotary encoder is used (not with ATmega8).
6. Automatic detection of NPN and PNP bipolar transistors, N- and P-Channel MOSFETs, JFETs, diodes, double diodes,N- and P-IGBTs, Thyristors and Triacs. For Thyristors and Triacs the ignition current and holding current must be reached with the tester. For IGBTs the 5V signal should be enough for driving the gate voltage.
7. Automatic detection of pin layout of the detected part.
8. Measuring of current amplification factor and Base-Emitter threshold voltage of bipolar transistors.
9. Darlington transistors can be identified by the threshold voltage and high current amplification factor.
10. Detection of the protection diode of bipolar transistors and MOSFETs.
11. Measuring of the Gate threshold voltage, the Gate capacity value and the RDSon at almost 5V gate voltage of MOSFETs.
12. Up to two Resistors are measured and shown with symbols | and values with up to four
decimal digits in the right dimension. All symbols are surrounded by the probe numbers of the Tester (1-3). So Potentiometer can also be measured. If the Potentiometer is adjusted to one of its ends, the Tester cannot differ the middle pin and the end pin.

13. Resolution of resistor measurement is now up to 0.01Ω, values up to 50MΩ are detected.
14. One capacitor can be detected and measured. It is shown with symbol | and value with
up to four decimal digits in the right dimension. The value can be from 25pF (8MHz clock, 50pF @1MHz clock) to 100mF. The resolution can be up to 1pF (@8MHz clock].
15. For capacitors with a capacity value above 20nF the Equivalent Serial Resistance (ESR) is measured with a resolution of 0.01Ω and is shown with two significant decimal digits. This feature is only available for ATmega with at least 16K flash memory.
16. For capacitors with a capacity value above 5000pF the voltage loss after a load pulse can be determined. The voltage loss give a hint for the quality factor of the capacitor.
17. Up to two diodes are shown with symbol | or symbol | in correct order. Additionally
the flux voltages are shown.
18. LED is detected as diode, the flux voltage is much higher than normal. Two-in-one LEDs are also detected as two diodes.
19. Zener-Diodes can be detected, if reverse break down Voltage is below 4.5V . These are shown as two diodes, you can identify this part only by the voltages. The outer probe numbers, which surround the diode symbols, are identical in this case. You can identify the real Anode of the diode only by the one with break down (threshold) Voltage nearby 700mV !
20. If more than 3 diode type parts are detected, the number of founded diodes is shown additionally to the fail message. This can only happen, if Diodes are attached to all three probes and at least one is a Z-Diode. In this case you should only connect two probes and start measurement again, one after the other.
21. Measurement of the capacity value of a single diode in reverse direction. Bipolar Transistors can also be analysed, if you connect the Base and only one of Collector or Emitter. If a ATmega with more than 8K flash memory is used, also the reverse current of the diode is measured with a resolution of 2nA. The value is only output to the screen, if it is greater than zero.
22. Only one measurement is needed to find out the connections of a bridge rectifier.
23. Capacitors with value below 25pF are usually not detectet, but can be measured together with a parallel diode or a parallel capacitor with at least 25pF. In this case you must subtract the capacity value of the parallel connected part. For processors with at least 32K flash memory the tester changeover to a special capacity meter function, if a capacitor with more than 25pF is once measured at TP1 and TP3. In this capacitor meter mode you can measure capacitors below 25pF at TP1 and TP3 directly.
24. For resistors below 2100Ω also the measurement of inductance will be done, if your ATmega
has at least 16K flash memory. For that a inductor icon | is shown behind the resistor
icon | . The range will be from about 0.01mH to more than 20H, but the accuracy is
not good. The measurement result is only shown with a single component connected.
25. Testing time is about two seconds, only capacity or inductance measurement can cause longer period.
26. Software can be configured to enable series of measurements before power will be shut down.
27. Build in selftest function with optional 50Hz Frequency generator to check the accuracy of clock frequency and wait calls (only for processors with at least 32K flash memory).

28. Selectable facility to calibrate the internal port resistance of port output and the zero offset of capacity measurement with the selftest (only for processors with at least 16K flash memory). A external capacitor with a value between 100nF and 20µF connected to pin 1 and pin 3 is necessary to compensate the offset voltage of the analog comparator. This can reduce measurement errors of capacitors of up to 40µF. With the same capacitor a correction voltage to the internal reference voltage is found to adjust the gain for ADC measuring with the internal reference.
29. Display the Collector cutoff current ICE0 with currentless base (1µA units) and Collector residual current ICES with base hold to emitter level (only for processors with at least 16K flash). This values are only shown, if they are not zero (especially for Germanium transistors).
30. For a ATmega with at least 32K flash memory the tester changes the operation modus from universal tester to a resistor tester, if only one resistor is detected at the test pin 1 (TP1) and test pin 3 (TP3). If you have selected the additional measurement of inductance for the resistor meter function with the Makefile option RMETER WITH L, also the inductance of components is measured in this mode. This special operating mode is indicated with a [R] or [RL] at the right side of the first display line. In the same way the tester changes to a capacity meter function, if a capacitor is detected at TP1 and TP3. This operation mode is indicated with a [C] at the right side of the first display line. With this capacity meter function capacity values are shown down to 1pF. Only for the automatic start you need a capacitor with more than 25pF. Both special modes can be finished by a key press. The tester will then continue with the normal tester function.
31. For processors with at least 32K flash a dialog function can be selected, which enable additional functions. Of course you can return from dialog to the normal Transistor Tester function.
32. With dialog function you can use a frequency measurement at port PD4 of the ATmega. The resolution is 1Hz for input frequencies above 25kHz. For lower frequencies the resolution can be up to 0.001mHz by measuring the mean period. You should read the the subsection Frequency measurement 2.2.4 at page 13 for details of connection a frequency signal.
33. With the dialog function and without the activated serial output a external voltage of up to 50V can be measured with the 10:1 voltage divider at the PC3 port. If the PLCC-Version of the ATmega328 is used, one of the additional pins can be used for the voltage measurement together with the serial output. If the zener diode measurement extension (DC-DC converter) is assembled, the measurement of zener diodes is also possible with this function by pressing the key.
34. With the dialog function a frequency output can be selected at the TP2 pin (PB2 Port of the ATmega). Currently a preselection of frequencies from 1Hz up to 2MHz can be selected.
35. With the dialog function a fixed frequency output with selectable pulse width can be activated at the TP2 pin (PB2 port of the ATmega). The width can be enhanced with 1% by a short key press or with 10% by a longer key press.
36. With the dialog function can be started a separated capacity measurement with ESR measurement. Capacities from about 2µF up to 50mF can most be measured in circuit, because only a little measurement voltage of about 300mV is used.
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

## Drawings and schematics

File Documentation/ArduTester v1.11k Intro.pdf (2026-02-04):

# Short description of the measurements with the Transistor Tester Version 1.11k

### Karl-Heinz K”ubbeler

kh kuebbeler@web.de

### March 16, 2021

# Contents

1 Description of BJT-measurements | 2
2 Description of MOSFET measurements | 6

# Chapter 1

# Description of BJT-measurements

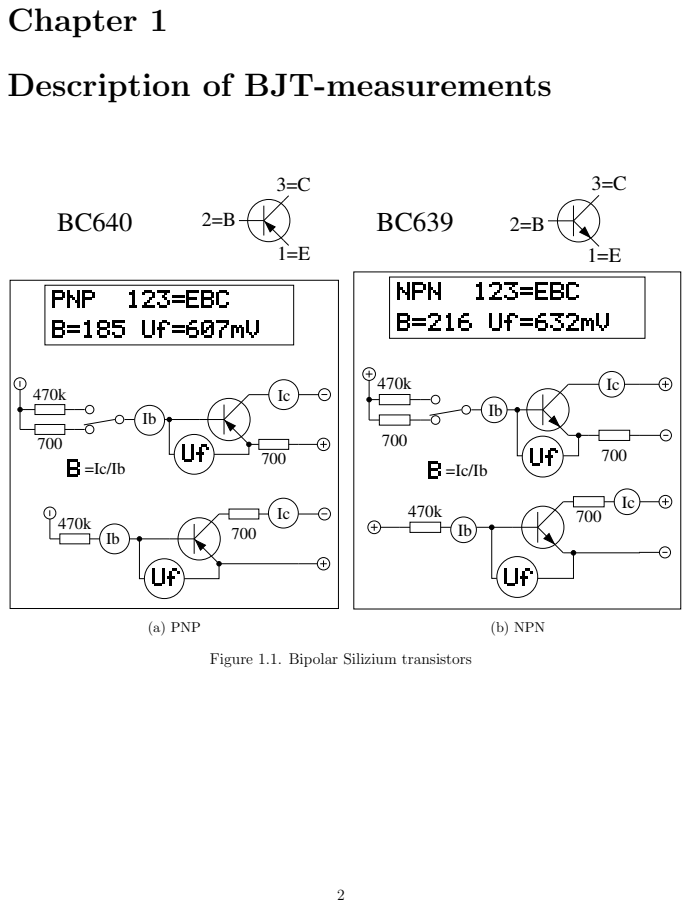
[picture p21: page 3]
(a) PNP; (b) NPN

Figure 1.1. Bipolar Silizium transistors

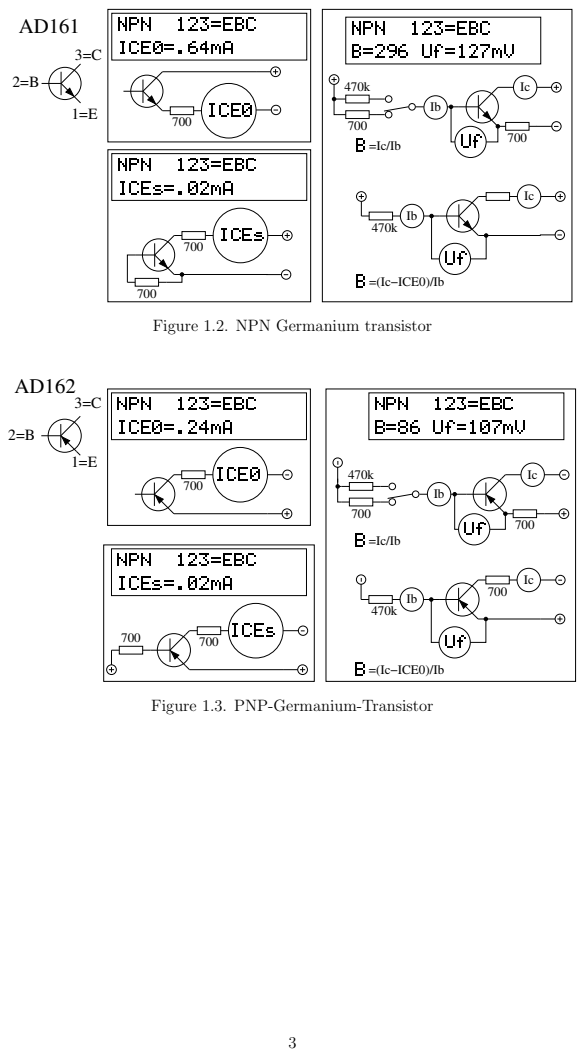
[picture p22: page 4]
=(Ic−ICE0)/Ib

Figure 1.2. NPN Germanium transistor

Figure 1.3. PNP-Germanium-Transistor

BC516

BC517

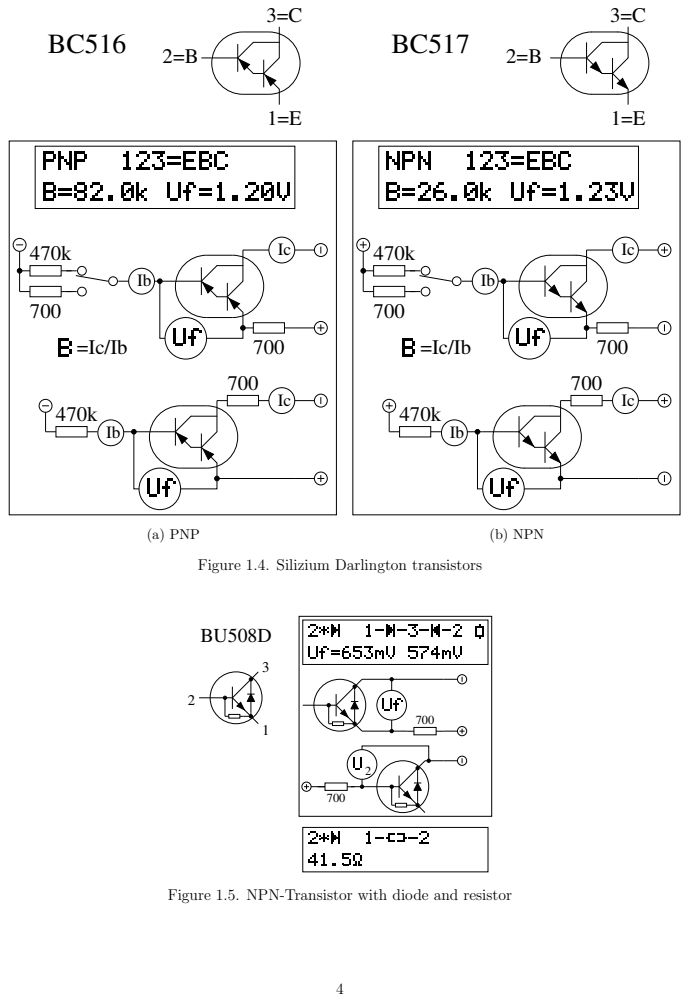
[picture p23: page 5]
(a) PNP; (b) NPN

Figure 1.4. Silizium Darlington transistors

Figure 1.5. NPN-Transistor with diode and resistor

## BDV64C

## BDV65C

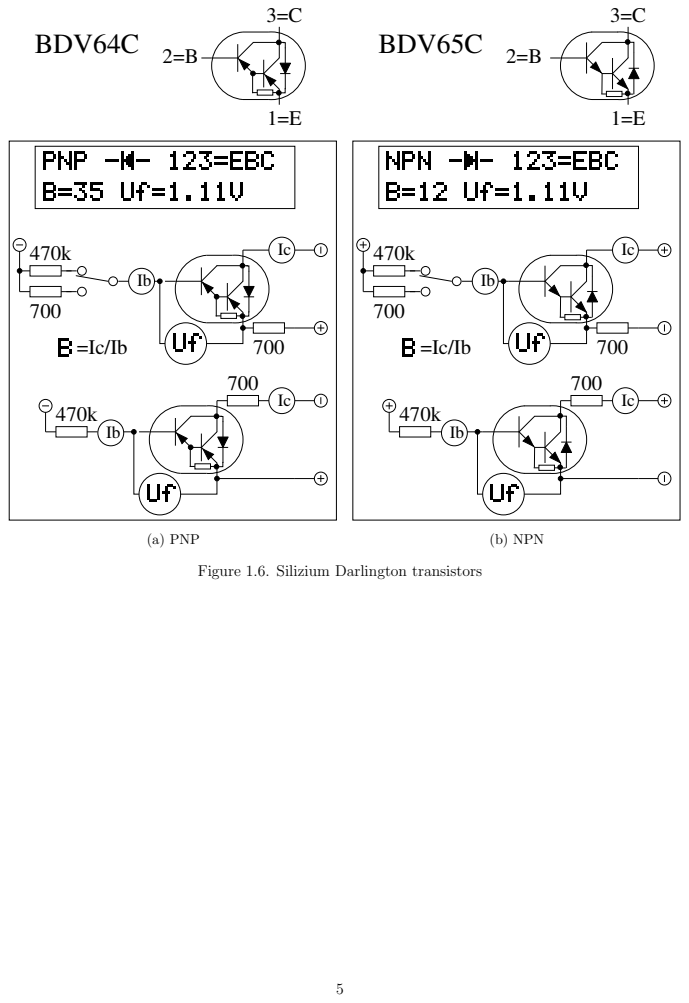
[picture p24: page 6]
(a) PNP; (b) NPN

Figure 1.6. Silizium Darlington transistors

# Chapter 2

# Description of MOSFET measurements

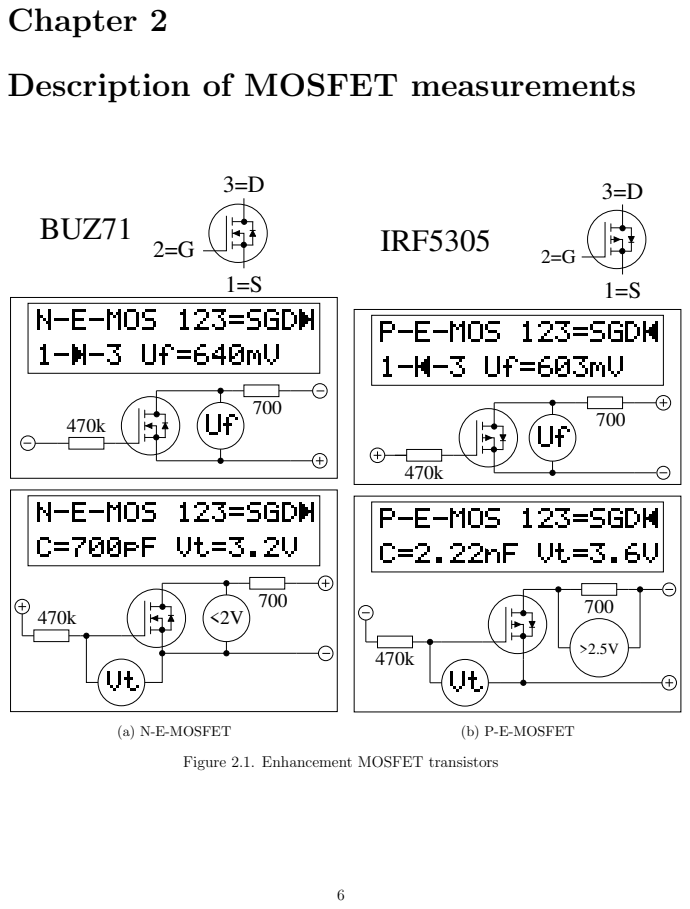
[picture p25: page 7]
BUZ71; (a) N-E-MOSFET; 2=G IRF5305; (b) P-E-MOSFET

Figure 2.1. Enhancement MOSFET transistors

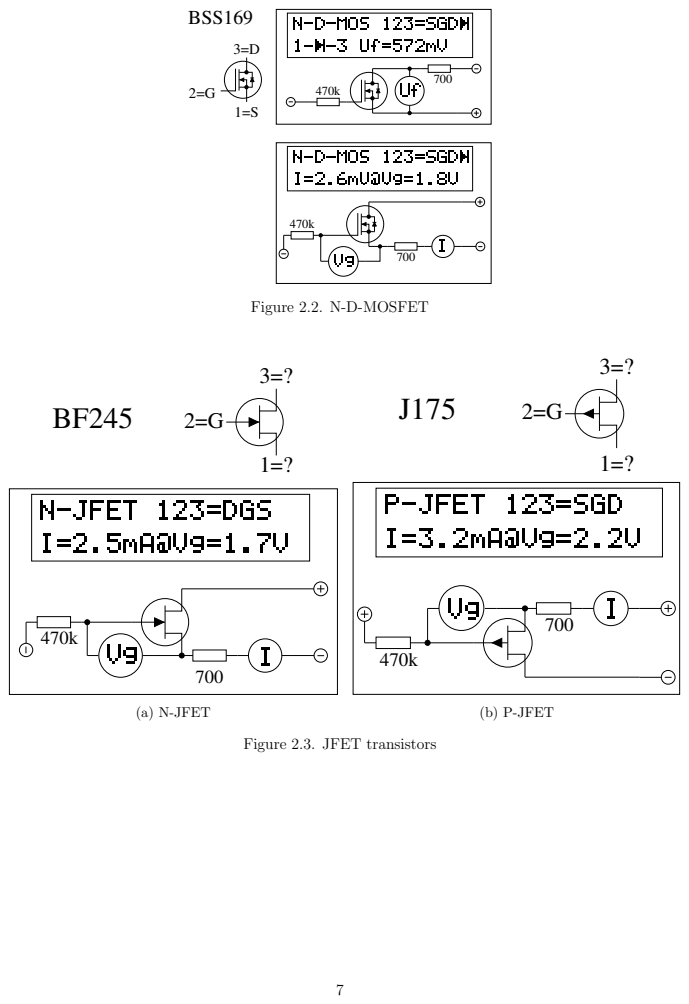
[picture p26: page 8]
BSS169; Figure 2.2. N-D-MOSFET; (a) N-JFET; (b) P-JFET

Figure 2.3. JFET transistors

# Bibliography

[1] Markus Frejek AVR-Transistortester,. Embedded Projects Journal, 11. Ausgabe, 2011
[2] Atmel Corporation 8-bit AVR with 8KBytes In-System Programmable Flash - ATmega8(L),. Manual, 2486Z-AVR-02/11, 2011
[3] Atmel Corporation 8-bit AVR with 4/8/16/32KBytes In-System Programmable Flash - ATmega48 - ATmega328,. Manual, 8271D-AVR-05/11, 2011
[4] http://en.wikibooks.org/wiki/LaTeX LaTeX documentation,. Guide to the LaTeX markup language, 2012
[5] Wikipedia | http://de.wikipedia.org/wiki/Equivalent_Series_Resistance | Erluterung
zum ESR. Normung und Ersatzschaltbild eines Kondensators, 2012
[6] http://www.xfig.org/userman Xfig documentation,. Documentation of the interactive drawing tool xfig, 2009
[7] http://docs.gimp.org/2.6/de gimp documentation. Documentation of the GNU Image Ma-nipolation Program, 2010
[8] http://www.mikrocontroller.net/articles/AVR-Transistortester Online documentation of the Transistor Tester, Online Article, 2009-2011
[9] http://www.mikrocontroller.net/articles/AVRDUDE Online documentation of the avrdude programmer interface, Online Article, 2004-2011
[10] http://www.mikrocontroller.net/topic/131804 Thread von Markus F., Forum thread, 2009
[11] http://www.mikrocontroller.net/articles/AVR_Transistortester Short decription of the TransistorTester von Karl-Heinz K., Online Article, 2012
[12] http://www.mikrocontroller.net/topic/248078 Thread von Karl-Heinz K., Thread and early Software versions, 2012

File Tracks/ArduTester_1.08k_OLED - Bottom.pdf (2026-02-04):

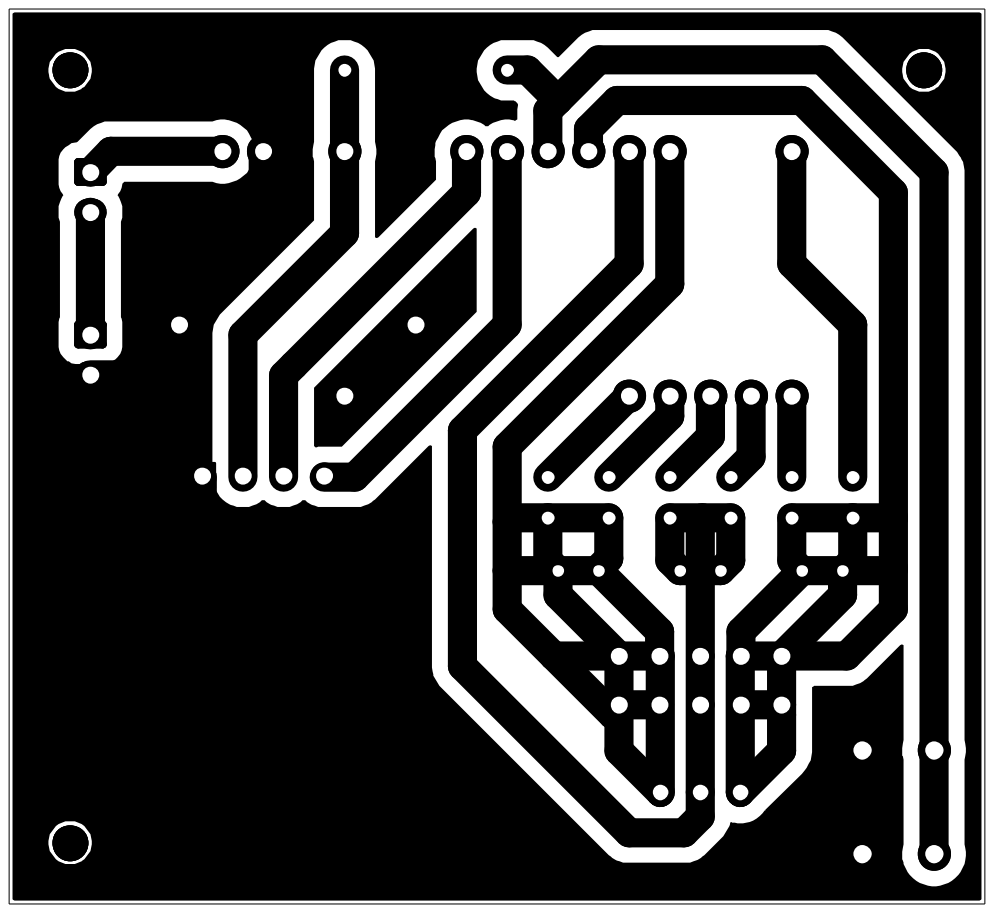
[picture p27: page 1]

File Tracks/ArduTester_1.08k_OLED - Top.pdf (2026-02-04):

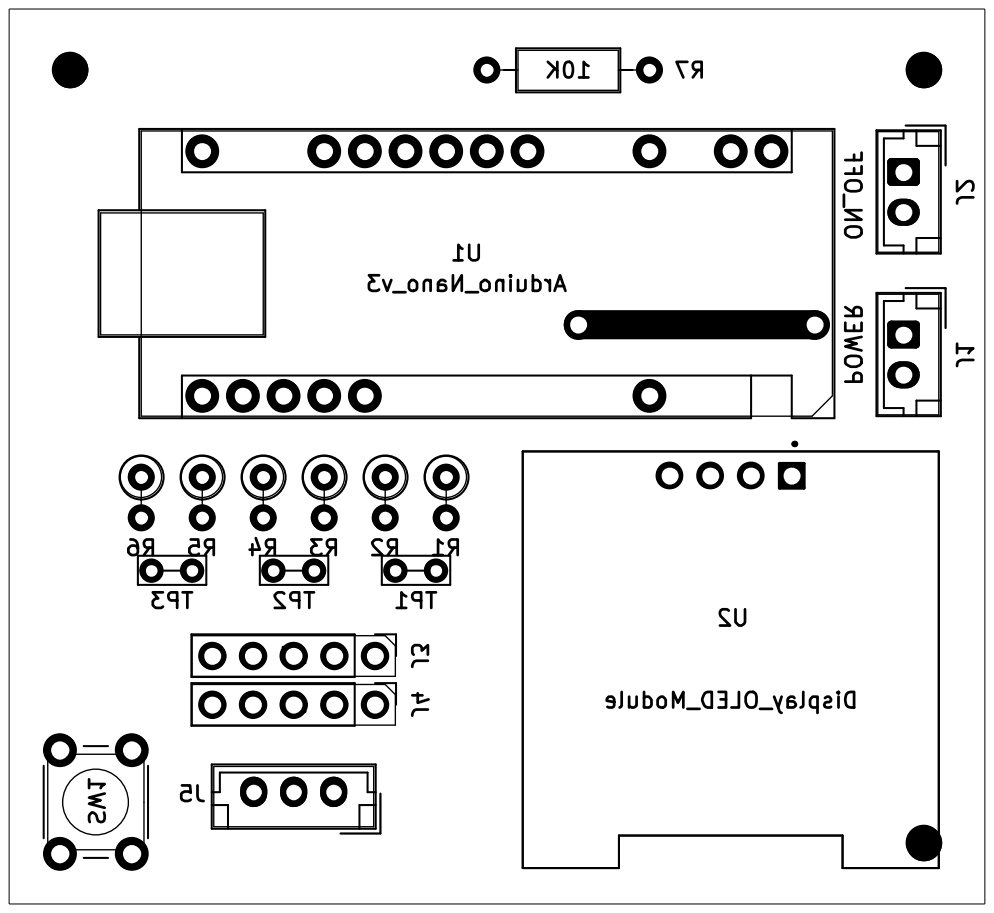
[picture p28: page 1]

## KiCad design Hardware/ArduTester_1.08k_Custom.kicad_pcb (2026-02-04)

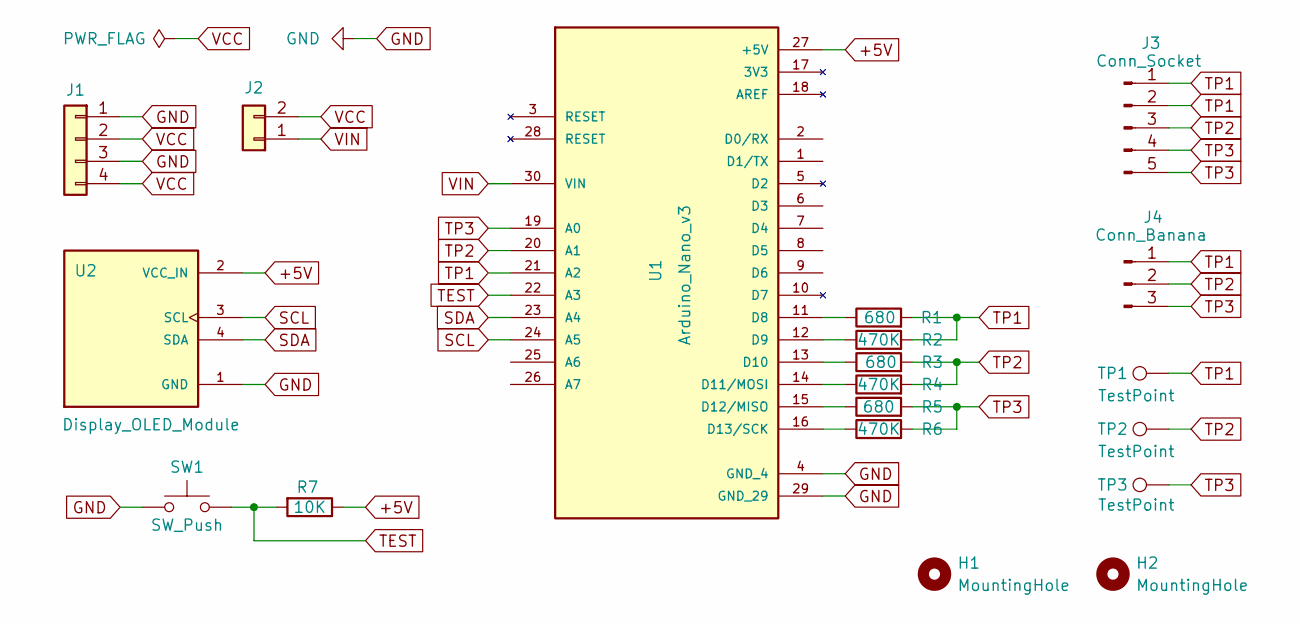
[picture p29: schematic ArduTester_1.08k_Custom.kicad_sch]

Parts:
H1, H2: MountingHole; MountingHole_2.2mm_M2
J1: POWER; JST_EH_B4B-EH-A_1x04_P2.50mm_Vertical
J2: SW_BTN; JST_EH_B2B-EH-A_1x02_P2.50mm_Vertical
J3: Conn_Socket; PinSocket_1x05_P2.54mm_Vertical
J4: Conn_Banana; JST_EH_B3B-EH-A_1x03_P2.50mm_Vertical
R1, R3, R5: 680; R_Axial_DIN0204_L3.6mm_D1.6mm_P7.62mm_Horizontal
R2, R4, R6: 470K; R_Axial_DIN0204_L3.6mm_D1.6mm_P7.62mm_Horizontal
R7: 10K; R_Axial_DIN0204_L3.6mm_D1.6mm_P7.62mm_Horizontal
SW1: SW_Push; SW_PUSH_6mm_H9.5mm
TP1, TP2, TP3: TestPoint; TestPoint_Bridge_Pitch2.54mm_Drill0.7mm
U1: Arduino_Nano_v3
U2: Display_OLED_Module; Display_OLED_Module_DM_OLED096_636

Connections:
+5V: R7.1, U1.27 (+5V), U2.2 (VCC_IN)
GND: J1.1, J1.3, SW1.1, U1.4 (GND_4), U1.29 (GND_29), U2.1 (GND)
unnamed: R1.1, U1.11 (D8)
unnamed: R2.1, U1.12 (D9)
unnamed: R3.1, U1.13 (D10)
unnamed: R4.1, U1.14 (D11/MOSI)
unnamed: R5.1, U1.15 (D12/MISO)
unnamed: R6.1, U1.16 (D13/SCK)
SCL: U1.24 (A5), U2.3 (SCL)
SDA: U1.23 (A4), U2.4 (SDA)
TEST: R7.2, SW1.2, U1.22 (A3)
TP1: J3.1, J3.2, J4.1, R1.2, R2.2, TP1.1, U1.21 (A2)
TP2: J3.3, J4.2, R3.2, R4.2, TP2.1, U1.20 (A1)
TP3: J3.4, J3.5, J4.3, R5.2, R6.2, TP3.1, U1.19 (A0)
VCC: J1.2, J1.4, J2.2
VIN: J2.1, U1.30 (VIN)

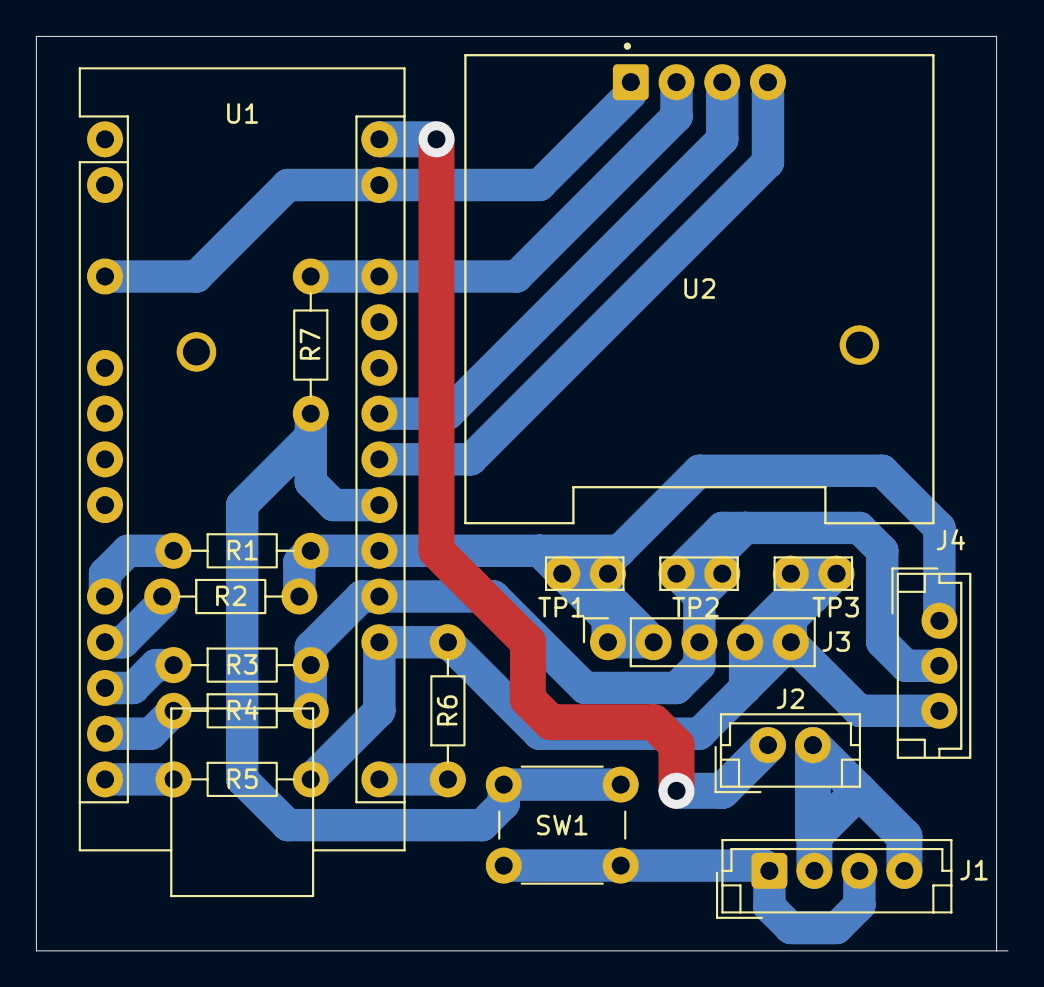
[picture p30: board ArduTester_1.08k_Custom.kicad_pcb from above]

Board: 2 copper layers, 54.0 x 50.8 mm, 19 parts (0 on the bottom side), 16 nets.

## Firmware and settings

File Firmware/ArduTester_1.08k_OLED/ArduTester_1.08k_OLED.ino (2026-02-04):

  /*                      \\\|///
                        \\  - -  //
                         (  @ @  )
  /--------------------oOOo-(_)-oOOo---------------------\
  |                                                      |
  |                                                      |
  |    Transistor Tester for Arduino (version 1.08a)     |
  |                                                      |
  |  based on code: Karl-Heinz Kubbeler (version 1.08k)  |
  |                                                      |
  |                                                      |
  |                            Oooo                      |
  \--------------------oooO----(   )---------------------/
                     (   )    ) /
                        \ (    (_/
                         \_)                            */


#include <avr/io.h>
#include <util/delay.h>
#include <avr/sleep.h>
#include <stdlib.h>
#include <string.h>
#include <avr/eeprom.h>
#include <avr/pgmspace.h>
#include <avr/wdt.h>
#include <avr/interrupt.h>
#include <math.h>
#include <stdint.h>
#include <avr/power.h>

//#define LCD1602
//#define LCD_I2C
//#define NOK5110
//#define OLED096
#define OLED_I2C

#ifdef LCD_I2C
  #ifndef LCD1602
    #define LCD1602
  #endif
#endif

#ifdef OLED_I2C
  #ifndef OLED096
    #define OLED096
  #endif
#endif

#ifdef LCD1602
  #ifdef LCD_I2C
    #include <Wire.h> 
    #include <LiquidCrystal_I2C.h>
  #else
    #include <LiquidCrystal.h>
  #endif
#endif

#ifdef NOK5110
  #include <SPI.h>
  #include <Adafruit_GFX.h>
  #include <Adafruit_PCD8544.h>
#endif

#ifdef OLED096
  #include <SPI.h>
  #include <Wire.h>
  #include <Adafruit_GFX.h>
  #include <Adafruit_SSD1306.h>
  #define TOP_ROW 4
#endif


// ******** config options for your Semiconductor tester

// Every changing of this Makefile will result in new compiling the whole
// programs, if you call make or make upload.

#define MCU atmega328p
#define F_CPU 16000000UL

// Select your language:
// Available languages are: LANG_ENGLISH, LANG_GERMAN, LANG_POLISH, LANG_CZECH, LANG_SLOVAK, LANG_SLOVENE,
//                          LANG_DUTCH, LANG_BRASIL, LANG_RUSSIAN, LANG_UKRAINIAN
#define LANG_ENGLISH

// The LCD_CYRILLIC option is necessary, if you have a display with cyrillic characterset.
// This lcd-display don't have a character for Ohm and for u (micro).
// Russian language requires a LCD controller with russian characterset and option LCD_CYRILLIC!
#define LCD_CYRILLIC

// The LCD_DOGM option must be set for support of the DOG-M type of LCD modules with ST7036 controller.
// For this LCD type the contrast must be set with software command.
//#define LCD_DOGM

// Option STRIP_GRID_BOARD selects different board-layout, do not set for standard board!
// The connection of LCD is totally different for both versions.
//#define STRIP_GRID_BOARD

// The WITH_SELFTEST option enables selftest function (only for mega168 or mega328).
//#define WITH_SELFTEST

// AUTO_CAL will enable the autocalibration of zero offset of capacity measurement and
// also the port output resistance values will be find out in SELFTEST section.
// With a external capacitor a additionally correction of reference voltage is figured out for 
// low capacity measurement and also for the AUTOSCALE_ADC measurement.
// The AUTO_CAL option is only selectable for mega168 and mega328.
//#define AUTO_CAL

// FREQUENCY_50HZ enables a 50 Hz frequency generator for up to one minute at the end of selftests.
//#define FREQUENCY_50HZ

// The WITH_AUTO_REF option enables reading of internal REF-voltage to get factors for the Capacity measuring.
#define WITH_AUTO_REF
// REF_C_KORR corrects the reference Voltage for capacity measurement (<40uF) and has mV units.
// Greater values gives lower capacity results.
#define REF_C_KORR 12
// REF_L_KORR corrects the reference Voltage for inductance measurement and has mV units.
#define REF_L_KORR 40
// C_H_KORR defines a correction of 0.1% units for big capacitor measurement.
// Positive values will reduce measurement results.
#define C_H_KORR 0

// The WITH_UART option enables the software UART (TTL level output at Pin PC3, 26).
// If the option is deselected, PC3 can be used as external voltage input with a
// 10:1 resistor divider.
//#define WITH_UART

// The CAP_EMPTY_LEVEL  defines the empty voltage level for capacitors in mV.
// Choose a higher value, if your Tester reports "Cell!" by unloading capacitors.
#define CAP_EMPTY_LEVEL 4

// The AUTOSCALE_ADC option enables the autoscale ADC (ADC use VCC and Bandgap Ref).
#define AUTOSCALE_ADC
#define REF_R_KORR 3

// The ESR_ZERO value define the zero value of ESR measurement (units = 0.01 Ohm).
//#define ESR_ZERO 29
#define ESR_ZERO 20

// NO_AREF_CAP tells your Software, that you have no Capacitor installed at pin AREF (21).
// This enables a shorter wait-time for AUTOSCALE_ADC function.
// A capacitor with 1nF can be used with the option NO_AREF_CAP set.
#define NO_AREF_CAP

// The OP_MHZ option tells the software the Operating Frequency of your ATmega.
// OP_MHZ 16

// Restart from sleep mode will be delayed for 16384 clock tics with crystal mode.
// Operation with the internal RC-Generator or external clock will delay the restart by only 6 clock tics.
// You must specify this with "#define RESTART_DELAY_TICS=6", if you don't use the crystal mode.
//#define RESTART_DELAY_TICS 6

// The USE_EEPROM option specify where you wish to locate fix text and tables.
// If USE_EEPROM is unset, program memory (flash) is taken for fix text and tables.
//#define USE_EEPROM

// Setting EBC_STYPE will select the old style to present the order of Transistor connection (EBC=...).
// Omitting the option will select the 123=... style.  Every point is replaced by a character identifying 
// type of connected transistor pin (B=Base, E=Emitter, C=Collector, G=Gate, S=Source, D=Drain).
// If you select EBC_STYLE=321 , the style will be 321=... , the inverted order to the 123=... style.
//#define EBC_STYLE
//#define EBC_STYLE 321

// Setting of NO_NANO avoids the use of n as prefix for Farad (nF), the mikro prefix is used insted (uF).
//#define NO_NANO

// The PULLUP_DISABLE option disable the pull-up Resistors of IO-Ports.
// To use this option a external pull-up Resistor (10k to 30k)
// from Pin 13 to VCC must be installed!
#define PULLUP_DISABLE

// The ANZ_MESS option specifies, how often an ADC value is read and accumulated.
// Possible values of ANZ_MESS are 5 to 200.
#define ANZ_MESS 25

// The POWER_OFF option enables the power off function, otherwise loop measurements infinitely
// until power is disconnected with a ON/OFF switch (#define POWER_OFF).
// If you have the tester without the power off transistors, you can deselect POWER_OFF .
// If you have NOT selected the POWER_OFF option with the transistors installed,
// you can stop measuring by holding the key several seconds after a result is
// displayed. After releasing the key, the tester will be shut off by timeout.
// Otherwise you can also specify, after how many measurements without found part
// the tester will shut down (#define POWER_OFF=5).
// The tester will also shut down with found part,
// but successfull measurements are allowed double of the specified number.
// You can specify up to 255 empty measurements (#define POWER_OFF=255).
//#define POWER_OFF 5
//#define POWER_OFF

// Option BAT_CHECK enables the Battery Voltage Check, otherwise the SW Version is displayed instead of Bat.
// BAT_CHECK should be set for battery powered tester version.
//#define BAT_CHECK

// The BAT_OUT option enables Battery Voltage Output on LCD (if BAT_CHECK is selected).
// If your 9V supply has a diode installed, use the BAT_OUT=600 form to specify the
// threshold voltage of your diode to adjust the output value.
// This threshold level is added to LCD-output and does not affect the voltage checking levels.
//#define BAT_OUT 150

// To adjust the warning-level and poor-level of battery check to the capability of a
// low drop voltage regulator, you can specify the Option BAT_POOR=5400 .
// The unit for this option value is 1mV , 5400 means a poor level of 5.4V.
// The warning level is 0.8V higher than the specified poor level (>5.3V).
// The warning level is 0.4V higher than the specified poor level (>2.9V, <=5.3V).
// The warning level is 0.2V higher than the specified poor level (>1.3V, <=2.9V).
// The warning level is 0.1V higher than the specified poor level (<=1.3V).
// Setting the poor level to low values is not recommended for rechargeable Batteries,
// because this increase the danger for deep discharge!!
#define BAT_POOR 6400

// The sleep mode of the ATmega168 or ATmega328 is normally used by the software to save current.
// You can inhibit this with the option INHIBIT_SLEEP_MODE .
//#define INHIBIT_SLEEP_MODE

// ******** end of selectable options

/* -=- -=- -=- -=- -=- -=- -=- -=- -=- -=- -=- -=- -=- -=- -=- -=- -=- -=- -=- -=- -=- -=- -=- -=- -=- -=- -=- -=- */

// ########  Configuration

#ifndef ADC_PORT
//#define DebugOut 3    // if set, output of voltages of resistor measurements in row 2,3,4
//#define DebugOut 4    // if set, output of voltages of Diode measurement in row 3+4
//#define DebugOut 5    // if set, output of Transistor checks in row 2+3
//#define DebugOut 10   // if set, output of capacity measurements (ReadCapacity) in row 3+4 

/*
  Port, that is directly connected to the probes.
  This Port must have an ADC-Input  (ATmega8:  PORTC).
  The lower pins of this Port must be used for measurements.
  Please don't change the definitions of TP1, TP2 and TP3!
  The TPREF pin can be connected with a 2.5V precision voltage reference
  The TPext can be used with a 10:1 resistor divider as external voltage probe up to 50V
*/

#define ADC_PORT PORTC
#define ADC_DDR DDRC
#define ADC_PIN PINC
#define TP1 0
#define TP2 1
#define TP3 2
#define TPext 3
// Port pin for 2.5V precision reference used for VCC check (optional)
#define TPREF 4
// Port pin for Battery voltage measuring
#define TPBAT 5

/*
  exact values of used resistors (Ohm).
  The standard value for R_L is 680 Ohm, for R_H 470kOhm.

  To calibrate your tester the resistor-values can be adjusted:
*/
#define R_L_VAL 6800          // standard value 680 Ohm, multiplied by 10 for 0.1 Ohm resolution
//#define R_L_VAL 6690        // this will be define a 669 Ohm
#define R_H_VAL 47000         // standard value 470000 Ohm, multiplied by 10, divided by 100 
//#define R_H_VAL 47900       // this will be define a 479000 Ohm, divided by 100 

#define R_DDR DDRB
#define R_PORT PORTB

/*
  Port for the Test resistors
  The Resistors must be connected to the lower 6 Pins of the Port in following sequence:
  RLx = 680R-resistor for Test-Pin x
  RHx = 470k-resistor for Test-Pin x

  RL1 an Pin 0
  RH1 an Pin 1
  RL2 an Pin 2
  RH2 an Pin 3
  RL3 an Pin 4
  RH3 an Pin 5
*/

#define ON_DDR DDRD
#define ON_PORT PORTD
#define ON_PIN_REG PIND
#define ON_PIN 18               // Pin, must be switched to high to switch power on

#ifdef STRIP_GRID_BOARD
// Strip Grid board version
  #define RST_PIN 0             // Pin, is switched to low, if push button is pressed
#else
// normal layout version
  #define RST_PIN 17            // Pin, is switched to low, if push button is pressed
#endif


// Port(s) / Pins for LCD

#ifdef STRIP_GRID_BOARD
  // special Layout for strip grid board
  #define HW_LCD_EN_PORT         PORTD
  #define HW_LCD_EN_PIN          5

  #define HW_LCD_RS_PORT         PORTD
  #define HW_LCD_RS_PIN          7

  #define HW_LCD_B4_PORT         PORTD
  #define HW_LCD_B4_PIN          4
  #define HW_LCD_B5_PORT         PORTD
  #define HW_LCD_B5_PIN          3
  #define HW_LCD_B6_PORT         PORTD
  #define HW_LCD_B6_PIN          2
  #define HW_LCD_B7_PORT         PORTD
  #define HW_LCD_B7_PIN          1
#else
  // normal Layout
  #define HW_LCD_EN_PORT         PORTD
  #define HW_LCD_EN_PIN          6

  #define HW_LCD_RS_PORT         PORTD
  #define HW_LCD_RS_PIN          7

  #define HW_LCD_B4_PORT         PORTD
  #define HW_LCD_B4_PIN          5
  #define HW_LCD_B5_PORT         PORTD
  #define HW_LCD_B5_PIN          4
  #define HW_LCD_B6_PORT         PORTD
  #define HW_LCD_B6_PIN          3
  #define HW_LCD_B7_PORT         PORTD
  #define HW_LCD_B7_PIN          2
#endif


// U_VCC defines the VCC Voltage of the ATmega in mV units

#define U_VCC 5000
// integer factors are used to change the ADC-value to mV resolution in ReadADC !

// With the option NO_CAP_HOLD_TIME you specify, that capacitor loaded with 680 Ohm resistor will not
// be tested to hold the voltage same time as load time.
// Otherwise (without this option) the voltage drop during load time is compensated to avoid displaying
// too much capacity for capacitors with internal parallel resistance.
// #define NO_CAP_HOLD_TIME


// U_SCALE can be set to 4 for better resolution of ReadADC function for resistor measurement
#define U_SCALE 4

// R_ANZ_MESS can be set to a higher number of measurements (up to 200) for resistor measurement
#define R_ANZ_MESS 190

// Watchdog
//#define WDT_enabled
/*
  If you remove the "#define WDT_enabled" , the Watchdog will not be activated.
  This is only for Test or debugging usefull.
  For normal operation please activate the Watchdog !
*/

// ########  End of configuration
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
void loop()
{
  // Entry: if start key is pressed before shut down
start:

  #ifdef NOK5110
    lcd.display();
  #endif

  #ifdef OLED096
    display.display();
  #endif

  TestKey = 1;
  while(TestKey) {
    TestKey = digitalRead(TestKeyPin);
    delay(100);
  }
  while(!TestKey) {
    TestKey = digitalRead(TestKeyPin);
    delay(100);
  }
  lcd_clear();
  delay(100);

  PartFound = PART_NONE;  // no part found
  NumOfDiodes = 0;    // Number of diodes = 0
  PartReady = 0;
  PartMode = 0;
  WithReference = 0;    // no precision reference voltage
  ADC_DDR = TXD_MSK;    // activate Software-UART 
  ResistorsFound = 0;   // no resistors found
  cap.ca = 0;
  cap.cb = 0;

  #ifdef WITH_UART
    uart_newline();   // start of new measurement
  #endif

  ADCconfig.RefFlag = 0;
  Calibrate_UR();   // get Ref Voltages and Pin resistance
  lcd_line1();    // 1 row
  
  ADCconfig.U_Bandgap = ADC_internal_reference;  // set internal reference voltage for ADC

  #ifdef BAT_CHECK
    // Battery check is selected
    ReadADC(TPBAT);     // Dummy-Readout
    trans.uBE[0] = W5msReadADC(TPBAT);  // with 5V reference
    lcd_fix_string(Bat_str);    // output: "Bat. "

    #ifdef BAT_OUT
      // display Battery voltage
      // The divisor to get the voltage in 0.01V units is ((10*33)/133) witch is about 2.4812
      // A good result can be get with multiply by 4 and divide by 10 (about 0.75%).
      //cap.cval = (trans.uBE[0]*4)/10+((BAT_OUT+5)/10); // usually output only 2 digits
      //DisplayValue(cap.cval,-2,'V',2);    // Display 2 Digits of this 10mV units
      cap.cval = (trans.uBE[0]*4)+BAT_OUT;    // usually output only 2 digits
      DisplayValue(cap.cval,-3,'V',2);      // Display 2 Digits of this 10mV units
      lcd_space();
    #endif

    #if (BAT_POOR > 12000)
      #warning "Battery POOR level is set very high!"
    #endif
    #if (BAT_POOR < 2500)
      #warning "Battery POOR level is set very low!"
    #endif

    #if (BAT_POOR > 5300)
      // use .8 V difference to Warn-Level
      #define WARN_LEVEL (((unsigned long)(BAT_POOR+800)*(unsigned long)33)/133)
    #elif (BAT_POOR > 3249)
      // less than 5.4 V only .4V difference to Warn-Level
      #define WARN_LEVEL (((unsigned long)(BAT_POOR+400)*(unsigned long)33)/133)
    #elif (BAT_POOR > 1299)
      // less than 2.9 V only .2V difference to Warn-Level
      #define WARN_LEVEL (((unsigned long)(BAT_POOR+200)*(unsigned long)33)/133)
    #else
      // less than 1.3 V only .1V difference to Warn-Level
      #define WARN_LEVEL (((unsigned long)(BAT_POOR+100)*(unsigned long)33)/133)
    #endif

    #define POOR_LEVEL (((unsigned long)(BAT_POOR)*(unsigned long)33)/133)

    // check the battery voltage
    if (trans.uBE[0] <  WARN_LEVEL) {

      // Vcc < 7,3V; show Warning 
      if(trans.uBE[0] < POOR_LEVEL) { 
        // Vcc <6,3V; no proper operation is possible
        lcd_fix_string(BatEmpty); // Battery empty!
        wait_about2s();
        PORTD = 0;      // switch power off
        return;
      }

      lcd_fix_string(BatWeak);    // Battery weak
    } else {                            // Battery-voltage OK
      lcd_fix_string(OK_str);     // "OK"
    }

  #else
    lcd_fix2_string(VERSION_str); // if no Battery check, Version .. in row 1
  #endif

  #ifdef WDT_enabled
    //wdt_enable(WDTO_2S);    // Watchdog on
  #endif

  //wait_about1s();     // add more time for reading batterie voltage

  // begin tests

  #ifdef AUTO_RH
    RefVoltage();     // compute RHmultip = f(reference voltage)
  #endif

  #if FLASHEND > 0x1fff
    if (WithReference) {
      // 2.5V precision reference is checked OK
      if ((mess_count == 0) && (empty_count == 0)) {
        // display VCC= only first time
        lcd_line2();
        lcd_fix_string(VCC_str);      // VCC=
        DisplayValue(ADCconfig.U_AVCC,-3,'V',3);  // Display 3 Digits of this mV units
        //lcd_space();
        //DisplayValue(RRpinMI,-1,LCD_CHAR_OMEGA,4);
        wait_about1s();
      }
    }
  #endif

  #ifdef WITH_VEXT
    // show the external voltage
    while (!(ON_PIN_REG & (1<<RST_PIN))) {
      lcd_line2();
      lcd_clear_line();
      lcd_line2();
      lcd_fix_string(Vext_str);     // Vext=
      ADC_DDR = 0;        // deactivate Software-UART
      trans.uBE[1] = W5msReadADC(TPext);  // read external voltage 
      ADC_DDR = TXD_MSK;      // activate Software-UART 

      #ifdef WITH_UART
        uart_newline();   // start of new measurement
      #endif

      DisplayValue(trans.uBE[1]*10,-3,'V',3); // Display 3 Digits of this mV units
      wait_about300ms();
    }
  #endif

  lcd_line2();      // LCD position row 2, column 1
  lcd_fix_string(TestRunning);  // String: testing...

  #ifndef DebugOut
    lcd_line2();    // LCD position row 2, column 1
  #endif

  #ifdef NOK5110
    lcd.display();
  #endif

  #ifdef OLED096
    display.display();
    display.setCursor(0,0);
  #endif

  delay(5);

  EntladePins();    // discharge all capacitors!

  if(PartFound == PART_CELL) {
    lcd_clear();
    lcd_fix_string(Cell_str); // display "Cell!"
    goto end2;
  }

  #ifdef CHECK_CALL
    AutoCheck();    // check, if selftest should be done
  #endif
     
  // check all 6 combinations for the 3 pins 
  //       High  Low  Tri
  CheckPins(TP1, TP2, TP3);
  CheckPins(TP2, TP1, TP3);
  CheckPins(TP1, TP3, TP2);
  CheckPins(TP3, TP1, TP2);
  CheckPins(TP2, TP3, TP1);
  CheckPins(TP3, TP2, TP1);
  
  // separate check if is is a capacitor
  if(((PartFound == PART_NONE) || (PartFound == PART_RESISTOR) || (PartFound == PART_DIODE)) ) {
    EntladePins();    // discharge capacities
    // measurement of capacities in all 3 combinations
    cap.cval_max = 0;   // set max to zero
    cap.cpre_max = -12;   // set max to pF unit

    ReadCapacity(TP3, TP1);
    ReadCapacity(TP3, TP2);
    ReadCapacity(TP2, TP1);

    #if FLASHEND > 0x1fff
      ReadInductance();   // measure inductance
    #endif
  }

  // All checks are done, output result to display
  lcd_clear();

  if(PartFound == PART_DIODE) {
    if(NumOfDiodes == 1) {    // single Diode
      //lcd_fix_string(Diode);    // "Diode: "

      #if FLASHEND > 0x1fff
        // enough memory to sort the pins

        #if EBC_STYLE == 321
          // the higher test pin number is left side
          if (diodes[0].Anode > diodes[0].Cathode) {
            lcd_testpin(diodes[0].Anode);
            lcd_fix_string(AnKat);          // "->|-"
            lcd_testpin(diodes[0].Cathode);
          } else {
            lcd_testpin(diodes[0].Cathode);
            lcd_fix_string(KatAn);          // "-|<-"
            lcd_testpin(diodes[0].Anode);
          }
        #else
          // the higher test pin number is right side
          if (diodes[0].Anode < diodes[0].Cathode) {
            lcd_testpin(diodes[0].Anode);
            lcd_fix_string(AnKat);          // "->|-"
            lcd_testpin(diodes[0].Cathode);
          } else {
            lcd_testpin(diodes[0].Cathode);
            lcd_fix_string(KatAn);          // "-|<-"
            lcd_testpin(diodes[0].Anode);
          }
        #endif

      #else
        // too less memory to sort the pins
        lcd_testpin(diodes[0].Anode);
        lcd_fix_string(AnKat);          // "->|-"
        lcd_testpin(diodes[0].Cathode);
      #endif

      #if FLASHEND > 0x1fff
        GetIr(diodes[0].Cathode,diodes[0].Anode);
      #endif

      UfOutput(0x70);

      #if defined(NOK5110) || defined(OLED096)
        lcd_line3();
      #endif

      // load current of capacity is (5V-1.1V)/(470000 Ohm) = 8298nA
      lcd_fix_string(GateCap_str);      // "C="
      ReadCapacity(diodes[0].Cathode,diodes[0].Anode);  // Capacity opposite flow direction
      DisplayValue(cap.cval,cap.cpre,'F',3);
      goto end;

    } else if(NumOfDiodes == 2) {   // double diode
      lcd_data('2');
      lcd_fix_string(Diodes);   // "diodes "

      if(diodes[0].Anode == diodes[1].Anode) { //Common Anode
        lcd_testpin(diodes[0].Cathode);
        lcd_fix_string(KatAn);          // "-|<-"
        lcd_testpin(diodes[0].Anode);
        lcd_fix_string(AnKat);          // "->|-"
        lcd_testpin(diodes[1].Cathode);
        UfOutput(0x01);
        goto end;

      } else if(diodes[0].Cathode == diodes[1].Cathode) { //Common Cathode
        lcd_testpin(diodes[0].Anode);
        lcd_fix_string(AnKat);          // "->|-"
        lcd_testpin(diodes[0].Cathode);
        lcd_fix_string(KatAn);          // "-|<-"
        lcd_testpin(diodes[1].Anode);
        UfOutput(0x01);
        goto end;
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

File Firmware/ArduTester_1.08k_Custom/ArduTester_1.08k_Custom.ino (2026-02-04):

#include <Wire.h>
#include "probes.h"
#include "resistors.h"
#include "display.h"
#include <Adafruit_GFX.h>
#include <Adafruit_SSD1306.h>

#define SCREEN_WIDTH    128
#define SCREEN_HEIGHT   64
#define SCREEN_ADDRESS  0x3C   // Dirección I2C (0x3C/0x3D)

Adafruit_SSD1306 display(SCREEN_WIDTH, SCREEN_HEIGHT, &Wire, -1);


void setup() {
  Serial.begin(9600);

  // inicializar el display
  if(!display.begin(SSD1306_SWITCHCAPVCC, SCREEN_ADDRESS)) {
    Serial.println(F("Error al inicializar SSD1306"));
    for(;;); // Detener si hay error
  }

  // limpiar buffer
  display.clearDisplay();
  display.setTextSize(2);
  display.setTextColor(SSD1306_WHITE); // Color blanco

  // bienvenida
  display.setCursor(0,0);
  display.println("R-TEST");
  display.display();
  
  delay(1000);
}

void loop() {

  long r12 = measureR(TP1, TP2);
  long r23 = measureR(TP2, TP3);
  long r13 = measureR(TP1, TP3);

  long best = -1;
  uint8_t A=0, B=0;

  long v[3] = {r12, r23, r13};
  uint8_t ta[3] = {1, 2, 1};
  uint8_t tb[3] = {2, 3, 3};

  for(int i=0; i<3; i++){
    if(v[i] > 0 && (best < 0 || v[i] < best)){
      best = v[i];
      A = ta[i];
      B = tb[i];
    }
  }

  showResistance(best, A, B);
  delay(300);
}

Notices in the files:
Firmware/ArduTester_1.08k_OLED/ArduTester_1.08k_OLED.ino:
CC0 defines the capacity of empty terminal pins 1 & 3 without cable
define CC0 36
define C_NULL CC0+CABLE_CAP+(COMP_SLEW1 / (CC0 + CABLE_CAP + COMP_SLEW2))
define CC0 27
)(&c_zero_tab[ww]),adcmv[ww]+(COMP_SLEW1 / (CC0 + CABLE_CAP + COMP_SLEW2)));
